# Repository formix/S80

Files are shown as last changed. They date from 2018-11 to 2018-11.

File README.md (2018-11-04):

# S80
## S80 - Stackable retro Z80 computer
Welcome to the primary source of information regarding the S80.

For in depth information on the S80 hardware, please visit: [S80 website](http://users.telenet.be/pynckels/s80_retro.html)

The S80 facebook page can be found at: [S80 on Facebook](https://www.facebook.com/S80computer)

The issues section of this repository will serve as discussion forum on everything around the S80 (actual and future hardware, actual and future software, inspirational ideas, questions, ...): [S80 community and forum](https://github.com/PaintedBlck/S80/issues)

We hope this is the beginning of a growing community of people around the S80 who want to inspire others, learn, help, discuss, ... See also the Code of Conduct, since this document describes how we see collaboration and having fun.

## S80C - Small Z80 Cp/m computer

This is a project in the making. The first discussions on the functionality have begun on the [S80 community and forum in Issue 12](https://github.com/PaintedBlck/S80/issues/12).

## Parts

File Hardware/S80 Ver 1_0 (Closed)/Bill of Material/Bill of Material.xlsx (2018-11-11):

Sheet: Bill of Material (Data)
PCB | Item | Item_value | Item_footprint | Item_name
/Breakout 2in/ | J801 | Header Female 02x20 Pins 11mm | Pynckels:PinSocket_2x20_P2.54mm_Vertical | Conn_02x20
/Breakout 2in/ | J802 | Header Female 01x08 Pins 11mm | Connector_PinSocket_2.54mm:PinSocket_1x08_P2.54mm_Vertical | Conn_01x08
/Breakout 2in/ | J803 | Header Female 01x08 Pins 11mm | Connector_PinSocket_2.54mm:PinSocket_1x08_P2.54mm_Vertical | Conn_01x08
/Breakout 2in/ | PCB | PCB | PCB 8 | PCB
/Breakout 2in/ | Screw | Screw M3 | PCB 8 | Screw
/Breakout 2in/ | Screw | Screw M3 | PCB 8 | Screw
/Breakout 2in/ | Screw | Screw M3 | PCB 8 | Screw
/Breakout 2in/ | Screw | Screw M3 | PCB 8 | Screw
/Breakout 2in/ | Screw | Screw M3 | PCB 8 | Screw
/Breakout 2in/ | Screw | Screw M3 | PCB 8 | Screw
/Breakout 2in/ | Screw | Screw M3 | PCB 8 | Screw
/Breakout 2in/ | Screw | Screw M3 | PCB 8 | Screw
/Breakout 2in/ | Spacer | Spacer 10mm 2xM3 inner | PCB 8 | Spacer
/Breakout 2in/ | Spacer | Spacer 10mm 2xM3 inner | PCB 8 | Spacer
/Breakout 2in/ | Spacer | Spacer 10mm 2xM3 inner | PCB 8 | Spacer
/Breakout 2in/ | Spacer | Spacer 10mm 2xM3 inner | PCB 8 | Spacer
/Breakout 7in/ | J901 | Header Female 02x20 Pins 11mm | Pynckels:PinSocket_2x20_P2.54mm_Vertical | Conn_02x20
/Breakout 7in/ | J902 | Header Female 01x08 Pins 11mm | Connector_PinSocket_2.54mm:PinSocket_1x08_P2.54mm_Vertical | Conn_01x08
/Breakout 7in/ | J903 | Header Female 01x08 Pins 11mm | Connector_PinSocket_2.54mm:PinSocket_1x08_P2.54mm_Vertical | Conn_01x08
/Breakout 7in/ | PCB | PCB | PCB 9 | PCB
/Breakout 7in/ | Screw | Screw M3 | PCB 9 | Screw
/Breakout 7in/ | Screw | Screw M3 | PCB 9 | Screw
/Breakout 7in/ | Screw | Screw M3 | PCB 9 | Screw
/Breakout 7in/ | Screw | Screw M3 | PCB 9 | Screw
/Breakout 7in/ | Screw | Screw M3 | PCB 9 | Screw
/Breakout 7in/ | Screw | Screw M3 | PCB 9 | Screw
/Breakout 7in/ | Screw | Screw M3 | PCB 9 | Screw
/Breakout 7in/ | Screw | Screw M3 | PCB 9 | Screw
/Breakout 7in/ | Spacer | Spacer 10mm 2xM3 inner | PCB 9 | Spacer
/Breakout 7in/ | Spacer | Spacer 10mm 2xM3 inner | PCB 9 | Spacer
/Breakout 7in/ | Spacer | Spacer 10mm 2xM3 inner | PCB 9 | Spacer
/Breakout 7in/ | Spacer | Spacer 10mm 2xM3 inner | PCB 9 | Spacer
/Clock Power Reset/ | C201 | 100pf min 10V | Capacitor_THT:C_Disc_D5.0mm_W2.5mm_P5.00mm | C
/Clock Power Reset/ | C202 | 100pf min 10V | Capacitor_THT:C_Disc_D5.0mm_W2.5mm_P5.00mm | C
/Clock Power Reset/ | C203 | 100pf min 10V | Capacitor_THT:C_Disc_D5.0mm_W2.5mm_P5.00mm | C
/Clock Power Reset/ | C204 | 100pf min 10V | Capacitor_THT:C_Disc_D5.0mm_W2.5mm_P5.00mm | C
/Clock Power Reset/ | C205 | 100pf min 10V | Capacitor_THT:C_Disc_D5.0mm_W2.5mm_P5.00mm | C
/Clock Power Reset/ | C206 | 100pf min 10V | Capacitor_THT:C_Disc_D5.0mm_W2.5mm_P5.00mm | C
/Clock Power Reset/ | C207 | 100pf min 10V | Capacitor_THT:C_Disc_D5.0mm_W2.5mm_P5.00mm | C
/Clock Power Reset/ | C208 | 100pf min 10V | Capacitor_THT:C_Disc_D5.0mm_W2.5mm_P5.00mm | C
/Clock Power Reset/ | C401 | 100pf min 10V | Capacitor_THT:C_Disc_D5.0mm_W2.5mm_P5.00mm | C
/Clock Power Reset/ | C601 | 22μF min 10V | Capacitor_THT:CP_Radial_D6.3mm_P2.50mm | C
/Clock Power Reset/ | C602 | 100pf min 10V | Capacitor_THT:C_Disc_D5.0mm_W2.5mm_P5.00mm | C
/Clock Power Reset/ | D201 | 5V1 | Pynckels:D_Zener_Reverse_Biased | D_Zener
/Clock Power Reset/ | D401 | 5V1 | Pynckels:D_Zener_Reverse_Biased | D_Zener
/Clock Power Reset/ | J201 | Header Female 02x20 Pins 11mm | Pynckels:PinSocket_2x20_P2.54mm_Vertical | Conn_02x20
/Clock Power Reset/ | J202 | Header Female 01x08 Pins 11mm | Connector_PinSocket_2.54mm:PinSocket_1x08_P2.54mm_Vertical | Conn_01x08
/Clock Power Reset/ | J203 | Header Female 01x08 Pins 11mm | Connector_PinSocket_2.54mm:PinSocket_1x08_P2.54mm_Vertical | Conn_01x08
/Clock Power Reset/ | J404 | Header Male 01x04 Pins 7mm | Connector_PinHeader_2.54mm:PinHeader_1x04_P2.54mm_Vertical | Jumper
/Clock Power Reset/ | JP201 | Header Male 02x01 Pins 7mm | Connector_PinHeader_2.54mm:PinHeader_1x02_P2.54mm_Vertical | Jumper
/Clock Power Reset/ | JP202 | Header Male 02x01 Pins 7mm | Connector_PinHeader_2.54mm:PinHeader_1x02_P2.54mm_Vertical | Jumper
/Clock Power Reset/ | JP203 | Header Male 02x01 Pins 7mm | Connector_PinHeader_2.54mm:PinHeader_1x02_P2.54mm_Vertical | Jumper
/Clock Power Reset/ | JP204 | Header Male 02x01 Pins 7mm | Connector_PinHeader_2.54mm:PinHeader_1x02_P2.54mm_Vertical | Jumper
/Clock Power Reset/ | JP205 | Header Male 02x01 Pins 7mm | Connector_PinHeader_2.54mm:PinHeader_1x02_P2.54mm_Vertical | Jumper
/Clock Power Reset/ | JP206 | Header Male 02x01 Pins 7mm | Connector_PinHeader_2.54mm:PinHeader_1x02_P2.54mm_Vertical | Jumper
/Clock Power Reset/ | JP207 | Header Male 02x01 Pins 7mm | Connector_PinHeader_2.54mm:PinHeader_1x02_P2.54mm_Vertical | Jumper
/Clock Power Reset/ | JP208 | Header Male 02x01 Pins 7mm | Connector_PinHeader_2.54mm:PinHeader_1x02_P2.54mm_Vertical | Jumper
/Clock Power Reset/ | Jumper | Jumper | Jumper | Jumper
/Clock Power Reset/ | PCB | PCB | PCB 2 4 6 | PCB
/Clock Power Reset/ | R601 | 1K 5% | Resistor_THT:R_Axial_DIN0207_L6.3mm_D2.5mm_P7.62mm_Horizontal | R
/Clock Power Reset/ | R602 | 1K 5% | Resistor_THT:R_Axial_DIN0207_L6.3mm_D2.5mm_P7.62mm_Horizontal | R
/Clock Power Reset/ | Screw | Screw M3 | PCB 2 4 6 | Screw
/Clock Power Reset/ | Screw | Screw M3 | PCB 2 4 6 | Screw
/Clock Power Reset/ | Screw | Screw M3 | PCB 2 4 6 | Screw
/Clock Power Reset/ | Screw | Screw M3 | PCB 2 4 6 | Screw
/Clock Power Reset/ | Screw | Screw M3 | PCB 2 4 6 | Screw
/Clock Power Reset/ | Screw | Screw M3 | PCB 2 4 6 | Screw
/Clock Power Reset/ | Screw | Screw M3 | PCB 2 4 6 | Screw
/Clock Power Reset/ | Screw | Screw M3 | PCB 2 4 6 | Screw
/Clock Power Reset/ | Spacer | Spacer 10mm 2xM3 inner | PCB 2 4 6 | Spacer
/Clock Power Reset/ | Spacer | Spacer 10mm 2xM3 inner | PCB 2 4 6 | Spacer
/Clock Power Reset/ | Spacer | Spacer 10mm 2xM3 inner | PCB 2 4 6 | Spacer
/Clock Power Reset/ | Spacer | Spacer 10mm 2xM3 inner | PCB 2 4 6 | Spacer
/Clock Power Reset/ | SW601 | Switch Push | Button_Switch_THT:SW_PUSH_6mm | Button
/Clock Power Reset/ | U601 | 74LS14 | Package_DIP:DIP-14_W7.62mm | Hex Inverter Schmitt Trigger74LS14
/Clock Power Reset/ | US601 | Socket 14-pin tulp | Package_DIP:DIP-14_W7.62mm | Socket 14-pin tulp
/Clock Power Reset/ | X207 | Oscillator 8Mhz | Oscillator:Oscillator_DIP-14 | XO32
/Memory/ | C301 | 100pf min 10V | Capacitor_THT:C_Disc_D5.0mm_W2.5mm_P5.00mm | C
/Memory/ | C302 | 100pf min 10V | Capacitor_THT:C_Disc_D5.0mm_W2.5mm_P5.00mm | C
/Memory/ | C303 | 100pf min 10V | Capacitor_THT:C_Disc_D5.0mm_W2.5mm_P5.00mm | C
/Memory/ | C304 | 100pf min 10V | Capacitor_THT:C_Disc_D5.0mm_W2.5mm_P5.00mm | C
/Memory/ | C305 | 100pf min 10V | Capacitor_THT:C_Disc_D5.0mm_W2.5mm_P5.00mm | C
/Memory/ | C306 | 100pf min 10V | Capacitor_THT:C_Disc_D5.0mm_W2.5mm_P5.00mm | C
/Memory/ | C307 | 100pf min 10V | Capacitor_THT:C_Disc_D5.0mm_W2.5mm_P5.00mm | C
/Memory/ | C308 | 100pf min 10V | Capacitor_THT:C_Disc_D5.0mm_W2.5mm_P5.00mm | C
/Memory/ | J301 | Header Female 02x20 Pins 11mm | Pynckels:PinSocket_2x20_P2.54mm_Vertical | Conn_02x20
/Memory/ | J302 | Header Female 01x08 Pins 11mm | Connector_PinSocket_2.54mm:PinSocket_1x08_P2.54mm_Vertical | Conn_01x08
/Memory/ | J303 | Header Female 01x08 Pins 11mm | Connector_PinSocket_2.54mm:PinSocket_1x08_P2.54mm_Vertical | Conn_01x08
/Memory/ | J304 | Header Male 02x08 Pins 7mm | Connector_PinHeader_2.54mm:PinHeader_2x08_P2.54mm_Vertical | Jumper
/Memory/ | J305 | Header Male 02x03 Pins 7mm | Connector_PinHeader_2.54mm:PinHeader_2x03_P2.54mm_Vertical | Jumper
/Memory/ | Jumper | Jumper | Jumper | Jumper
/Memory/ | Jumper | Jumper | Jumper | Jumper
/Memory/ | Jumper | Jumper | Jumper | Jumper
/Memory/ | Jumper | Jumper | Jumper | Jumper
/Memory/ | Jumper | Jumper | Jumper | Jumper
/Memory/ | Jumper | Jumper | Jumper | Jumper
/Memory/ | Jumper | Jumper | Jumper | Jumper
/Memory/ | Jumper | Jumper | Jumper | Jumper
/Memory/ | Jumper | Jumper | Jumper | Jumper
/Memory/ | PCB | PCB | PCB 3 | PCB
/Memory/ | R301 | 220 5% | Resistor_THT:R_Axial_DIN0207_L6.3mm_D2.5mm_P7.62mm_Horizontal | R
/Memory/ | R302 | 220 5% | Resistor_THT:R_Axial_DIN0207_L6.3mm_D2.5mm_P7.62mm_Horizontal | R
/Memory/ | R303 | 220 5% | Resistor_THT:R_Axial_DIN0207_L6.3mm_D2.5mm_P7.62mm_Horizontal | R
/Memory/ | R304 | 220 5% | Resistor_THT:R_Axial_DIN0207_L6.3mm_D2.5mm_P7.62mm_Horizontal | R
/Memory/ | R305 | 220 5% | Resistor_THT:R_Axial_DIN0207_L6.3mm_D2.5mm_P7.62mm_Horizontal | R
/Memory/ | R306 | 220 5% | Resistor_THT:R_Axial_DIN0207_L6.3mm_D2.5mm_P7.62mm_Horizontal | R
/Memory/ | R307 | 220 5% | Resistor_THT:R_Axial_DIN0207_L6.3mm_D2.5mm_P7.62mm_Horizontal | R
/Memory/ | R308 | 220 5% | Resistor_THT:R_Axial_DIN0207_L6.3mm_D2.5mm_P7.62mm_Horizontal | R
/Memory/ | R309 | 5K 5% | Resistor_THT:R_Axial_DIN0207_L6.3mm_D2.5mm_P7.62mm_Horizontal | R
/Memory/ | R310 | 5K 5% | Resistor_THT:R_Axial_DIN0207_L6.3mm_D2.5mm_P7.62mm_Horizontal | R
/Memory/ | R311 | 5K 5% | Resistor_THT:R_Axial_DIN0207_L6.3mm_D2.5mm_P7.62mm_Horizontal | R
/Memory/ | Screw | Screw M3 | PCB 3 | Screw
/Memory/ | Screw | Screw M3 | PCB 3 | Screw
/Memory/ | Screw | Screw M3 | PCB 3 | Screw
/Memory/ | Screw | Screw M3 | PCB 3 | Screw
/Memory/ | Screw | Screw M3 | PCB 3 | Screw
/Memory/ | Screw | Screw M3 | PCB 3 | Screw
/Memory/ | Screw | Screw M3 | PCB 3 | Screw
/Memory/ | Screw | Screw M3 | PCB 3 | Screw
/Memory/ | Spacer | Spacer 10mm 2xM3 inner | PCB 3 | Spacer
/Memory/ | Spacer | Spacer 10mm 2xM3 inner | PCB 3 | Spacer
/Memory/ | Spacer | Spacer 10mm 2xM3 inner | PCB 3 | Spacer
/Memory/ | Spacer | Spacer 10mm 2xM3 inner | PCB 3 | Spacer
/Memory/ | U301 | 74LS32 | Package_DIP:DIP-14_W7.62mm | Quad 2 Input OR Gate 74LS32
/Memory/ | U302 | AT28C256 | Package_DIP:DIP-28_W15.24mm | AT28C256-15PC
/Memory/ | U303 | 74LS04 | Package_DIP:DIP-14_W7.62mm | Hex Inverter 74LS04
/Memory/ | U304 | AT28C256 | Package_DIP:DIP-28_W15.24mm | AT28C256-15PC
/Memory/ | U305 | AT28C256 | Package_DIP:DIP-28_W15.24mm | AT28C256-15PC
/Memory/ | U306 | HM62256 | Package_DIP:DIP-28_W15.24mm | HM62256
/Memory/ | U307 | HM62256 | Package_DIP:DIP-28_W15.24mm | HM62256
/Memory/ | U308 | 74LS682 | Package_DIP:DIP-20_W7.62mm | 8-bit Magnitude Comparator 74LS682
/Memory/ | US301 | Socket 14-pin tulp | Package_DIP:DIP-14_W7.62mm | Socket 14-pin tulp
/Memory/ | US302 | Socket 28-pin tulp | Package_DIP:DIP-28_W15.24mm | Socket 28-pin tulp
/Memory/ | US303 | Socket 14-pin tulp | Package_DIP:DIP-14_W7.62mm | Socket 14-pin tulp
/Memory/ | US304 | Socket 28-pin tulp | Package_DIP:DIP-28_W15.24mm | Socket 28-pin tulp
/Memory/ | US305 | Socket 28-pin tulp | Package_DIP:DIP-28_W15.24mm | Socket 28-pin tulp
/Memory/ | US306 | Socket 28-pin tulp | Package_DIP:DIP-28_W15.24mm | Socket 28-pin tulp
/Memory/ | US306 | Socket 28-pin tulp | Package_DIP:DIP-28_W15.24mm | Socket 28-pin tulp
/Memory/ | US308 | Socket 20-pin tulp | Package_DIP:DIP-20_W7.62mm | Socket 20-pin tulp
/Processor/ | C501 | 100pf min 10V | Capacitor_THT:C_Disc_D5.0mm_W2.5mm_P5.00mm | C
/Processor/ | C502 | 100pf min 10V | Capacitor_THT:C_Disc_D5.0mm_W2.5mm_P5.00mm | C
/Processor/ | C503 | 100pf min 10V | Capacitor_THT:C_Disc_D5.0mm_W2.5mm_P5.00mm | C
/Processor/ | C504 | 100pf min 10V | Capacitor_THT:C_Disc_D5.0mm_W2.5mm_P5.00mm | C
/Processor/ | C505 | 100pf min 10V | Capacitor_THT:C_Disc_D5.0mm_W2.5mm_P5.00mm | C
/Processor/ | C506 | 100pf min 10V | Capacitor_THT:C_Disc_D5.0mm_W2.5mm_P5.00mm | C
/Processor/ | D501 | D | Pynckels:D_1N4148_Reverse_Biased | D
/Processor/ | D502 | D | Pynckels:D_1N4148_Reverse_Biased | D
/Processor/ | D503 | D | Pynckels:D_1N4148_Reverse_Biased | D
/Processor/ | D504 | D | Pynckels:D_1N4148_Reverse_Biased | D
/Processor/ | D505 | D | Pynckels:D_1N4148_Reverse_Biased | D
/Processor/ | D506 | D | Pynckels:D_1N4148_Reverse_Biased | D
/Processor/ | D507 | D | Pynckels:D_1N4148_Reverse_Biased | D
/Processor/ | D508 | D | Pynckels:D_1N4148_Reverse_Biased | D
/Processor/ | D509 | D | Pynckels:D_1N4148_Reverse_Biased | D
/Processor/ | D510 | D | Pynckels:D_1N4148_Reverse_Biased | D
/Processor/ | D511 | D | Pynckels:D_1N4148_Reverse_Biased | D
/Processor/ | D512 | D | Pynckels:D_1N4148_Reverse_Biased | D
/Processor/ | J501 | Header Female 02x20 Pins 11mm | Pynckels:PinSocket_2x20_P2.54mm_Vertical | Conn_02x20
/Processor/ | J502 | Header Female 01x08 Pins 11mm | Connector_PinSocket_2.54mm:PinSocket_1x08_P2.54mm_Vertical | Conn_01x08
/Processor/ | J503 | Header Female 01x08 Pins 11mm | Connector_PinSocket_2.54mm:PinSocket_1x08_P2.54mm_Vertical | Conn_01x08
/Processor/ | PCB | PCB | PCB 5 | PCB
/Processor/ | R501 | 5K 5% | Resistor_THT:R_Axial_DIN0207_L6.3mm_D2.5mm_P7.62mm_Horizontal | R
/Processor/ | R502 | 5K 5% | Resistor_THT:R_Axial_DIN0207_L6.3mm_D2.5mm_P7.62mm_Horizontal | R
/Processor/ | R503 | 5K 5% | Resistor_THT:R_Axial_DIN0207_L6.3mm_D2.5mm_P7.62mm_Horizontal | R
/Processor/ | R504 | 5K 5% | Resistor_THT:R_Axial_DIN0207_L6.3mm_D2.5mm_P7.62mm_Horizontal | R
/Processor/ | R505 | 5K 5% | Resistor_THT:R_Axial_DIN0207_L6.3mm_D2.5mm_P7.62mm_Horizontal | R
/Processor/ | R506 | 5K 5% | Resistor_THT:R_Axial_DIN0207_L6.3mm_D2.5mm_P7.62mm_Horizontal | R
/Processor/ | R507 | 220 5% | Resistor_THT:R_Axial_DIN0207_L6.3mm_D2.5mm_P7.62mm_Horizontal | R
/Processor/ | R508 | 220 5% | Resistor_THT:R_Axial_DIN0207_L6.3mm_D2.5mm_P7.62mm_Horizontal | R
/Processor/ | R509 | 220 5% | Resistor_THT:R_Axial_DIN0207_L6.3mm_D2.5mm_P7.62mm_Horizontal | R
/Processor/ | R510 | 220 5% | Resistor_THT:R_Axial_DIN0207_L6.3mm_D2.5mm_P7.62mm_Horizontal | R
/Processor/ | R511 | 220 5% | Resistor_THT:R_Axial_DIN0207_L6.3mm_D2.5mm_P7.62mm_Horizontal | R
/Processor/ | R512 | 220 5% | Resistor_THT:R_Axial_DIN0207_L6.3mm_D2.5mm_P7.62mm_Horizontal | R
/Processor/ | Screw | Screw M3 | PCB 5 | Screw
/Processor/ | Screw | Screw M3 | PCB 5 | Screw
/Processor/ | Screw | Screw M3 | PCB 5 | Screw
/Processor/ | Screw | Screw M3 | PCB 5 | Screw
/Processor/ | Screw | Screw M3 | PCB 5 | Screw
/Processor/ | Screw | Screw M3 | PCB 5 | Screw
/Processor/ | Screw | Screw M3 | PCB 5 | Screw
/Processor/ | Screw | Screw M3 | PCB 5 | Screw
/Processor/ | Spacer | Spacer 10mm 2xM3 inner | PCB 5 | Spacer
/Processor/ | Spacer | Spacer 10mm 2xM3 inner | PCB 5 | Spacer
/Processor/ | Spacer | Spacer 10mm 2xM3 inner | PCB 5 | Spacer
/Processor/ | Spacer | Spacer 10mm 2xM3 inner | PCB 5 | Spacer
/Processor/ | U501 | Z80CPU | Package_DIP:DIP-40_W15.24mm | Z80CPU
/Processor/ | U502 | 74LS04 | Package_DIP:DIP-14_W7.62mm | Hex Inverter 74LS04
/Processor/ | U503 | 74LS244 | Package_DIP:DIP-20_W7.62mm | Octal Buffer 74LS244
/Processor/ | U504 | 74LS244 | Package_DIP:DIP-20_W7.62mm | Octal Buffer 74LS244
/Processor/ | U505 | 74LS245 | Package_DIP:DIP-20_W7.62mm | Octal Bus Tranceiver 74LS245
/Processor/ | U506 | 74LS244 | Package_DIP:DIP-20_W7.62mm | Octal Buffer 74LS244
/Processor/ | US501 | Socket 40-pin tulp | Package_DIP:DIP-40_W15.24mm | Socket 40-pin tulp
/Processor/ | US502 | Socket 14-pin tulp | Package_DIP:DIP-14_W7.62mm | Socket 14-pin tulp
/Processor/ | US503 | Socket 20-pin tulp | Package_DIP:DIP-20_W7.62mm | Socket 20-pin tulp
/Processor/ | US504 | Socket 20-pin tulp | Package_DIP:DIP-20_W7.62mm | Socket 20-pin tulp
/Processor/ | US505 | Socket 20-pin tulp | Package_DIP:DIP-20_W7.62mm | Socket 20-pin tulp
/Processor/ | US506 | Socket 20-pin tulp | Package_DIP:DIP-20_W7.62mm | Socket 20-pin tulp
/Serial/ | C701 | 100pf min 10V | Capacitor_THT:C_Disc_D5.0mm_W2.5mm_P5.00mm | C
/Serial/ | C702 | 100pf min 10V | Capacitor_THT:C_Disc_D5.0mm_W2.5mm_P5.00mm | C
/Serial/ | C703 | 100pf min 10V | Capacitor_THT:C_Disc_D5.0mm_W2.5mm_P5.00mm | C
/Serial/ | C704 | 100pf min 10V | Capacitor_THT:C_Disc_D5.0mm_W2.5mm_P5.00mm | C
/Serial/ | J701 | Header Female 02x20 Pins 11mm | Pynckels:PinSocket_2x20_P2.54mm_Vertical | Conn_02x20
/Serial/ | J702 | Header Female 01x08 Pins 11mm | Connector_PinSocket_2.54mm:PinSocket_1x08_P2.54mm_Vertical | Conn_01x08
/Serial/ | J703 | Header Female 01x08 Pins 11mm | Connector_PinSocket_2.54mm:PinSocket_1x08_P2.54mm_Vertical | Conn_01x08
/Serial/ | J704 | Header Male 02x05 Pins 7mm | Connector_PinHeader_2.54mm:PinHeader_2x05_P2.54mm_Vertical | Jumper
/Serial/ | Jumper | Jumper | Jumper | Jumper
/Serial/ | Jumper | Jumper | Jumper | Jumper
/Serial/ | Jumper | Jumper | Jumper | Jumper
/Serial/ | Jumper | Jumper | Jumper | Jumper
/Serial/ | Jumper | Jumper | Jumper | Jumper
/Serial/ | PCB | PCB | PCB 7 | PCB
/Serial/ | R701 | 5K 5% | Resistor_THT:R_Axial_DIN0207_L6.3mm_D2.5mm_P7.62mm_Horizontal | R
/Serial/ | R702 | 5K 5% | Resistor_THT:R_Axial_DIN0207_L6.3mm_D2.5mm_P7.62mm_Horizontal | R
/Serial/ | R703 | 5K 5% | Resistor_THT:R_Axial_DIN0207_L6.3mm_D2.5mm_P7.62mm_Horizontal | R
/Serial/ | R704 | 5K 5% | Resistor_THT:R_Axial_DIN0207_L6.3mm_D2.5mm_P7.62mm_Horizontal | R
/Serial/ | R705 | 5K 5% | Resistor_THT:R_Axial_DIN0207_L6.3mm_D2.5mm_P7.62mm_Horizontal | R
/Serial/ | Screw | Screw M3 | PCB 7 | Screw
/Serial/ | Screw | Screw M3 | PCB 7 | Screw
/Serial/ | Screw | Screw M3 | PCB 7 | Screw
/Serial/ | Screw | Screw M3 | PCB 7 | Screw
/Serial/ | Screw | Screw M3 | PCB 7 | Screw
/Serial/ | Screw | Screw M3 | PCB 7 | Screw
/Serial/ | Screw | Screw M3 | PCB 7 | Screw
/Serial/ | Screw | Screw M3 | PCB 7 | Screw
/Serial/ | Spacer | Spacer 10mm 2xM3 inner | PCB 7 | Spacer
/Serial/ | Spacer | Spacer 10mm 2xM3 inner | PCB 7 | Spacer
/Serial/ | Spacer | Spacer 10mm 2xM3 inner | PCB 7 | Spacer
/Serial/ | Spacer | Spacer 10mm 2xM3 inner | PCB 7 | Spacer
/Serial/ | U701 | 16C550 | Package_DIP:DIP-40_W15.24mm | USART 16C550
/Serial/ | U702 | 74LS04 | Package_DIP:DIP-14_W7.62mm | Hex Inverter 74LS04
/Serial/ | U703 | 74LS682 | Package_DIP:DIP-20_W7.62mm | 8-bit Magnitude Comparator 74LS682
/Serial/ | US701 | Socket 40-pin tulp | Package_DIP:DIP-40_W15.24mm | Socket 40-pin tulp
/Serial/ | US702 | Socket 14-pin tulp | Package_DIP:DIP-14_W7.62mm | Socket 14-pin tulp
/Serial/ | US703 | Socket 20-pin tulp | Package_DIP:DIP-20_W7.62mm | Socket 20-pin tulp
/Serial/ | X701 | Oscillator 1.8432Mhz | Oscillator:Oscillator_DIP-14 | XO32
Test Point Breakout 2in (option) | Brk801 | Test Point | Pynckels:pad_0_8mm_1_5mm | Vero Loop Terminal 01x01 1.02mm
Test Point Breakout 2in (option) | Brk802 | Test Point | Pynckels:pad_0_8mm_1_5mm | Vero Loop Terminal 01x01 1.02mm
Test Point Breakout 2in (option) | Brk803 | Test Point | Pynckels:pad_0_8mm_1_5mm | Vero Loop Terminal 01x01 1.02mm
Test Point Breakout 2in (option) | Brk804 | Test Point | Pynckels:pad_0_8mm_1_5mm | Vero Loop Terminal 01x01 1.02mm
Test Point Breakout 2in (option) | Brk805 | Test Point | Pynckels:pad_0_8mm_1_5mm | Vero Loop Terminal 01x01 1.02mm
Test Point Breakout 2in (option) | Brk806 | Test Point | Pynckels:pad_0_8mm_1_5mm | Vero Loop Terminal 01x01 1.02mm
Test Point Breakout 2in (option) | Brk807 | Test Point | Pynckels:pad_0_8mm_1_5mm | Vero Loop Terminal 01x01 1.02mm
Test Point Breakout 2in (option) | Brk808 | Test Point | Pynckels:pad_0_8mm_1_5mm | Vero Loop Terminal 01x01 1.02mm
Test Point Breakout 2in (option) | Brk809 | Test Point | Pynckels:pad_0_8mm_1_5mm | Vero Loop Terminal 01x01 1.02mm
Test Point Breakout 2in (option) | Brk810 | Test Point | Pynckels:pad_0_8mm_1_5mm | Vero Loop Terminal 01x01 1.02mm
Test Point Breakout 2in (option) | Brk811 | Test Point | Pynckels:pad_0_8mm_1_5mm | Vero Loop Terminal 01x01 1.02mm
Test Point Breakout 2in (option) | Brk812 | Test Point | Pynckels:pad_0_8mm_1_5mm | Vero Loop Terminal 01x01 1.02mm
Test Point Breakout 2in (option) | Brk813 | Test Point | Pynckels:pad_0_8mm_1_5mm | Vero Loop Terminal 01x01 1.02mm
Test Point Breakout 2in (option) | Brk814 | Test Point | Pynckels:pad_0_8mm_1_5mm | Vero Loop Terminal 01x01 1.02mm
Test Point Breakout 2in (option) | Brk815 | Test Point | Pynckels:pad_0_8mm_1_5mm | Vero Loop Terminal 01x01 1.02mm
Test Point Breakout 2in (option) | Brk816 | Test Point | Pynckels:pad_0_8mm_1_5mm | Vero Loop Terminal 01x01 1.02mm
Test Point Breakout 2in (option) | Brk817 | Test Point | Pynckels:pad_0_8mm_1_5mm | Vero Loop Terminal 01x01 1.02mm
Test Point Breakout 2in (option) | Brk818 | Test Point | Pynckels:pad_0_8mm_1_5mm | Vero Loop Terminal 01x01 1.02mm
Test Point Breakout 2in (option) | Brk819 | Test Point | Pynckels:pad_0_8mm_1_5mm | Vero Loop Terminal 01x01 1.02mm
Test Point Breakout 2in (option) | Brk820 | Test Point | Pynckels:pad_0_8mm_1_5mm | Vero Loop Terminal 01x01 1.02mm
Test Point Breakout 2in (option) | Brk821 | Test Point | Pynckels:pad_0_8mm_1_5mm | Vero Loop Terminal 01x01 1.02mm
Test Point Breakout 2in (option) | Brk822 | Test Point | Pynckels:pad_0_8mm_1_5mm | Vero Loop Terminal 01x01 1.02mm
Test Point Breakout 2in (option) | Brk823 | Test Point | Pynckels:pad_0_8mm_1_5mm | Vero Loop Terminal 01x01 1.02mm
Test Point Breakout 2in (option) | Brk824 | Test Point | Pynckels:pad_0_8mm_1_5mm | Vero Loop Terminal 01x01 1.02mm
Test Point Breakout 2in (option) | Brk825 | Test Point | Pynckels:pad_0_8mm_1_5mm | Vero Loop Terminal 01x01 1.02mm
Test Point Breakout 2in (option) | Brk826 | Test Point | Pynckels:pad_0_8mm_1_5mm | Vero Loop Terminal 01x01 1.02mm
Test Point Breakout 2in (option) | Brk827 | Test Point | Pynckels:pad_0_8mm_1_5mm | Vero Loop Terminal 01x01 1.02mm
Test Point Breakout 2in (option) | Brk828 | Test Point | Pynckels:pad_0_8mm_1_5mm | Vero Loop Terminal 01x01 1.02mm
Test Point Breakout 2in (option) | Brk829 | Test Point | Pynckels:pad_0_8mm_1_5mm | Vero Loop Terminal 01x01 1.02mm
Test Point Breakout 2in (option) | Brk830 | Test Point | Pynckels:pad_0_8mm_1_5mm | Vero Loop Terminal 01x01 1.02mm
Test Point Breakout 2in (option) | Brk831 | Test Point | Pynckels:pad_0_8mm_1_5mm | Vero Loop Terminal 01x01 1.02mm
Test Point Breakout 2in (option) | Brk832 | Test Point | Pynckels:pad_0_8mm_1_5mm | Vero Loop Terminal 01x01 1.02mm
Test Point Breakout 2in (option) | Brk833 | Test Point | Pynckels:pad_0_8mm_1_5mm | Vero Loop Terminal 01x01 1.02mm
Test Point Breakout 2in (option) | Brk834 | Test Point | Pynckels:pad_0_8mm_1_5mm | Vero Loop Terminal 01x01 1.02mm
Test Point Breakout 2in (option) | Brk835 | Test Point | Pynckels:pad_0_8mm_1_5mm | Vero Loop Terminal 01x01 1.02mm
Test Point Breakout 2in (option) | Brk836 | Test Point | Pynckels:pad_0_8mm_1_5mm | Vero Loop Terminal 01x01 1.02mm
Test Point Breakout 2in (option) | Brk837 | Test Point | Pynckels:pad_0_8mm_1_5mm | Vero Loop Terminal 01x01 1.02mm
Test Point Breakout 2in (option) | Brk838 | Test Point | Pynckels:pad_0_8mm_1_5mm | Vero Loop Terminal 01x01 1.02mm
Test Point Breakout 2in (option) | Brk839 | Test Point | Pynckels:pad_0_8mm_1_5mm | Vero Loop Terminal 01x01 1.02mm
Test Point Breakout 2in (option) | Brk840 | Test Point | Pynckels:pad_0_8mm_1_5mm | Vero Loop Terminal 01x01 1.02mm
Test Point Breakout 2in (option) | Brk841 | Test Point | Pynckels:pad_0_8mm_1_5mm | Vero Loop Terminal 01x01 1.02mm
Test Point Breakout 2in (option) | Brk842 | Test Point | Pynckels:pad_0_8mm_1_5mm | Vero Loop Terminal 01x01 1.02mm
Test Point Breakout 2in (option) | Brk843 | Test Point | Pynckels:pad_0_8mm_1_5mm | Vero Loop Terminal 01x01 1.02mm
Test Point Breakout 2in (option) | Brk844 | Test Point | Pynckels:pad_0_8mm_1_5mm | Vero Loop Terminal 01x01 1.02mm
Test Point Breakout 2in (option) | Brk845 | Test Point | Pynckels:pad_0_8mm_1_5mm | Vero Loop Terminal 01x01 1.02mm
Test Point Breakout 2in (option) | Brk846 | Test Point | Pynckels:pad_0_8mm_1_5mm | Vero Loop Terminal 01x01 1.02mm
Test Point Breakout 2in (option) | Brk847 | Test Point | Pynckels:pad_0_8mm_1_5mm | Vero Loop Terminal 01x01 1.02mm
Test Point Breakout 2in (option) | Brk848 | Test Point | Pynckels:pad_0_8mm_1_5mm | Vero Loop Terminal 01x01 1.02mm
Test Point Breakout 2in (option) | Brk849 | Test Point | Pynckels:pad_0_8mm_1_5mm | Vero Loop Terminal 01x01 1.02mm
Test Point Breakout 2in (option) | Brk850 | Test Point | Pynckels:pad_0_8mm_1_5mm | Vero Loop Terminal 01x01 1.02mm
Test Point Breakout 2in (option) | Brk851 | Test Point | Pynckels:pad_0_8mm_1_5mm | Vero Loop Terminal 01x01 1.02mm
Test Point Breakout 2in (option) | Brk852 | Test Point | Pynckels:pad_0_8mm_1_5mm | Vero Loop Terminal 01x01 1.02mm
Test Point Breakout 2in (option) | Brk853 | Test Point | Pynckels:pad_0_8mm_1_5mm | Vero Loop Terminal 01x01 1.02mm
Test Point Breakout 2in (option) | Brk854 | Test Point | Pynckels:pad_0_8mm_1_5mm | Vero Loop Terminal 01x01 1.02mm
Test Point Breakout 2in (option) | Brk855 | Test Point | Pynckels:pad_0_8mm_1_5mm | Vero Loop Terminal 01x01 1.02mm
Test Point Breakout 2in (option) | Brk856 | Test Point | Pynckels:pad_0_8mm_1_5mm | Vero Loop Terminal 01x01 1.02mm
Test Point Breakout 7in (option) | Brk901 | Test Point | Pynckels:pad_0_8mm_1_5mm | Vero Loop Terminal 01x01 1.02mm
Test Point Breakout 7in (option) | Brk902 | Test Point | Pynckels:pad_0_8mm_1_5mm | Vero Loop Terminal 01x01 1.02mm
Test Point Breakout 7in (option) | Brk903 | Test Point | Pynckels:pad_0_8mm_1_5mm | Vero Loop Terminal 01x01 1.02mm
Test Point Breakout 7in (option) | Brk904 | Test Point | Pynckels:pad_0_8mm_1_5mm | Vero Loop Terminal 01x01 1.02mm
Test Point Breakout 7in (option) | Brk905 | Test Point | Pynckels:pad_0_8mm_1_5mm | Vero Loop Terminal 01x01 1.02mm
Test Point Breakout 7in (option) | Brk906 | Test Point | Pynckels:pad_0_8mm_1_5mm | Vero Loop Terminal 01x01 1.02mm
Test Point Breakout 7in (option) | Brk907 | Test Point | Pynckels:pad_0_8mm_1_5mm | Vero Loop Terminal 01x01 1.02mm
Test Point Breakout 7in (option) | Brk908 | Test Point | Pynckels:pad_0_8mm_1_5mm | Vero Loop Terminal 01x01 1.02mm
Test Point Breakout 7in (option) | Brk909 | Test Point | Pynckels:pad_0_8mm_1_5mm | Vero Loop Terminal 01x01 1.02mm
Test Point Breakout 7in (option) | Brk910 | Test Point | Pynckels:pad_0_8mm_1_5mm | Vero Loop Terminal 01x01 1.02mm
Test Point Breakout 7in (option) | Brk911 | Test Point | Pynckels:pad_0_8mm_1_5mm | Vero Loop Terminal 01x01 1.02mm
Test Point Breakout 7in (option) | Brk912 | Test Point | Pynckels:pad_0_8mm_1_5mm | Vero Loop Terminal 01x01 1.02mm
Test Point Breakout 7in (option) | Brk913 | Test Point | Pynckels:pad_0_8mm_1_5mm | Vero Loop Terminal 01x01 1.02mm
Test Point Breakout 7in (option) | Brk914 | Test Point | Pynckels:pad_0_8mm_1_5mm | Vero Loop Terminal 01x01 1.02mm
Test Point Breakout 7in (option) | Brk915 | Test Point | Pynckels:pad_0_8mm_1_5mm | Vero Loop Terminal 01x01 1.02mm
Test Point Breakout 7in (option) | Brk916 | Test Point | Pynckels:pad_0_8mm_1_5mm | Vero Loop Terminal 01x01 1.02mm
Test Point Breakout 7in (option) | Brk917 | Test Point | Pynckels:pad_0_8mm_1_5mm | Vero Loop Terminal 01x01 1.02mm
Test Point Breakout 7in (option) | Brk918 | Test Point | Pynckels:pad_0_8mm_1_5mm | Vero Loop Terminal 01x01 1.02mm
Test Point Breakout 7in (option) | Brk919 | Test Point | Pynckels:pad_0_8mm_1_5mm | Vero Loop Terminal 01x01 1.02mm
Test Point Breakout 7in (option) | Brk920 | Test Point | Pynckels:pad_0_8mm_1_5mm | Vero Loop Terminal 01x01 1.02mm
Test Point Breakout 7in (option) | Brk921 | Test Point | Pynckels:pad_0_8mm_1_5mm | Vero Loop Terminal 01x01 1.02mm
Test Point Breakout 7in (option) | Brk922 | Test Point | Pynckels:pad_0_8mm_1_5mm | Vero Loop Terminal 01x01 1.02mm
Test Point Breakout 7in (option) | Brk923 | Test Point | Pynckels:pad_0_8mm_1_5mm | Vero Loop Terminal 01x01 1.02mm
Test Point Breakout 7in (option) | Brk924 | Test Point | Pynckels:pad_0_8mm_1_5mm | Vero Loop Terminal 01x01 1.02mm
Test Point Breakout 7in (option) | Brk925 | Test Point | Pynckels:pad_0_8mm_1_5mm | Vero Loop Terminal 01x01 1.02mm
Test Point Breakout 7in (option) | Brk926 | Test Point | Pynckels:pad_0_8mm_1_5mm | Vero Loop Terminal 01x01 1.02mm
Test Point Breakout 7in (option) | Brk927 | Test Point | Pynckels:pad_0_8mm_1_5mm | Vero Loop Terminal 01x01 1.02mm
Test Point Breakout 7in (option) | Brk928 | Test Point | Pynckels:pad_0_8mm_1_5mm | Vero Loop Terminal 01x01 1.02mm
Test Point Breakout 7in (option) | Brk929 | Test Point | Pynckels:pad_0_8mm_1_5mm | Vero Loop Terminal 01x01 1.02mm
Test Point Breakout 7in (option) | Brk930 | Test Point | Pynckels:pad_0_8mm_1_5mm | Vero Loop Terminal 01x01 1.02mm
Test Point Breakout 7in (option) | Brk931 | Test Point | Pynckels:pad_0_8mm_1_5mm | Vero Loop Terminal 01x01 1.02mm
Test Point Breakout 7in (option) | Brk932 | Test Point | Pynckels:pad_0_8mm_1_5mm | Vero Loop Terminal 01x01 1.02mm
Test Point Breakout 7in (option) | Brk933 | Test Point | Pynckels:pad_0_8mm_1_5mm | Vero Loop Terminal 01x01 1.02mm
Test Point Breakout 7in (option) | Brk934 | Test Point | Pynckels:pad_0_8mm_1_5mm | Vero Loop Terminal 01x01 1.02mm
Test Point Breakout 7in (option) | Brk935 | Test Point | Pynckels:pad_0_8mm_1_5mm | Vero Loop Terminal 01x01 1.02mm
Test Point Breakout 7in (option) | Brk936 | Test Point | Pynckels:pad_0_8mm_1_5mm | Vero Loop Terminal 01x01 1.02mm
Test Point Breakout 7in (option) | Brk937 | Test Point | Pynckels:pad_0_8mm_1_5mm | Vero Loop Terminal 01x01 1.02mm
Test Point Breakout 7in (option) | Brk938 | Test Point | Pynckels:pad_0_8mm_1_5mm | Vero Loop Terminal 01x01 1.02mm
Test Point Breakout 7in (option) | Brk939 | Test Point | Pynckels:pad_0_8mm_1_5mm | Vero Loop Terminal 01x01 1.02mm
Test Point Breakout 7in (option) | Brk940 | Test Point | Pynckels:pad_0_8mm_1_5mm | Vero Loop Terminal 01x01 1.02mm
Test Point Breakout 7in (option) | Brk941 | Test Point | Pynckels:pad_0_8mm_1_5mm | Vero Loop Terminal 01x01 1.02mm
Test Point Breakout 7in (option) | Brk942 | Test Point | Pynckels:pad_0_8mm_1_5mm | Vero Loop Terminal 01x01 1.02mm
Test Point Breakout 7in (option) | Brk943 | Test Point | Pynckels:pad_0_8mm_1_5mm | Vero Loop Terminal 01x01 1.02mm
Test Point Breakout 7in (option) | Brk944 | Test Point | Pynckels:pad_0_8mm_1_5mm | Vero Loop Terminal 01x01 1.02mm
Test Point Breakout 7in (option) | Brk945 | Test Point | Pynckels:pad_0_8mm_1_5mm | Vero Loop Terminal 01x01 1.02mm
Test Point Breakout 7in (option) | Brk946 | Test Point | Pynckels:pad_0_8mm_1_5mm | Vero Loop Terminal 01x01 1.02mm
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

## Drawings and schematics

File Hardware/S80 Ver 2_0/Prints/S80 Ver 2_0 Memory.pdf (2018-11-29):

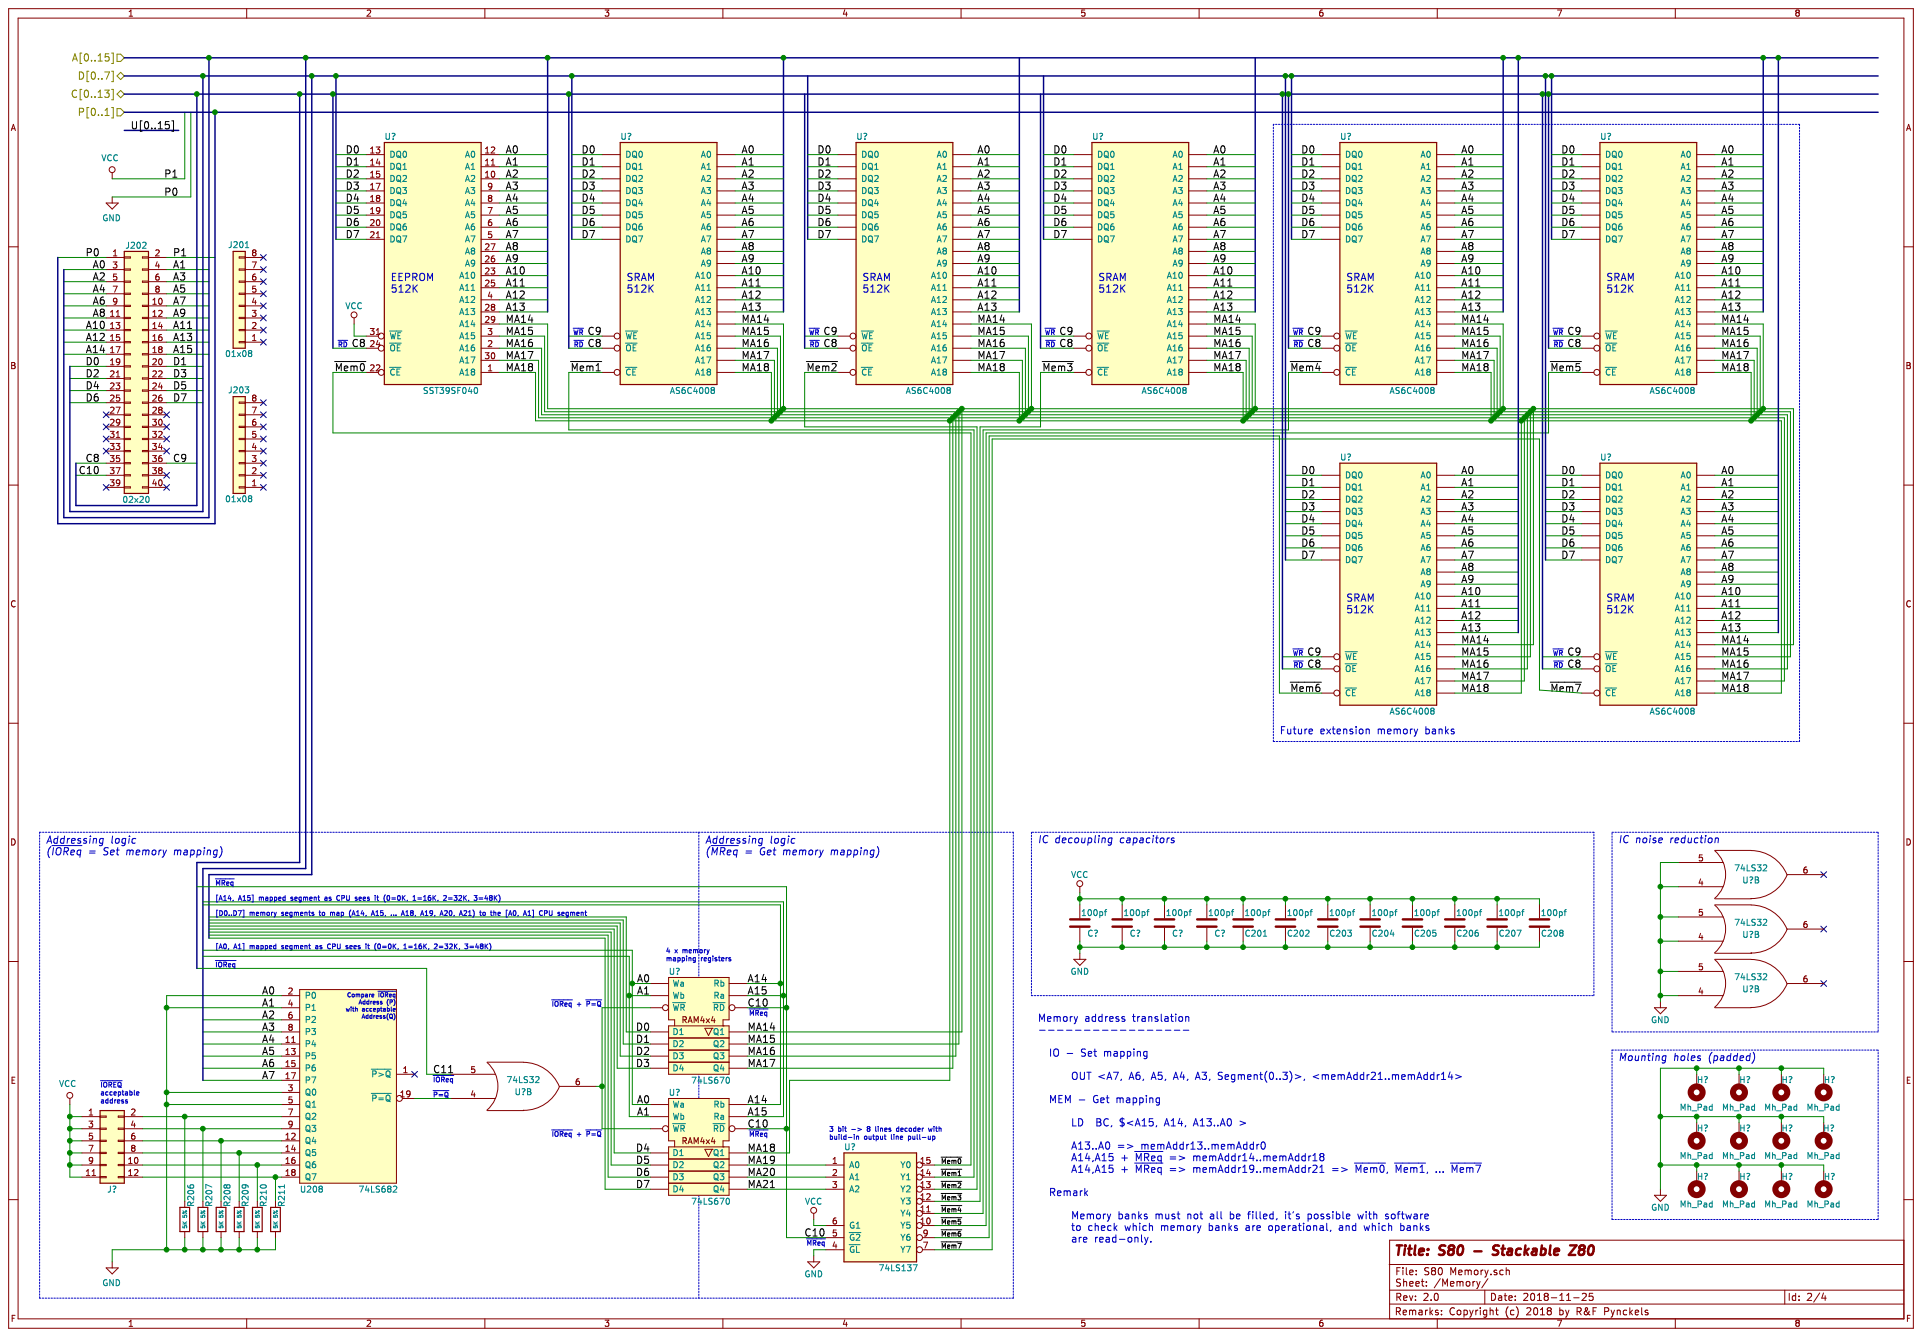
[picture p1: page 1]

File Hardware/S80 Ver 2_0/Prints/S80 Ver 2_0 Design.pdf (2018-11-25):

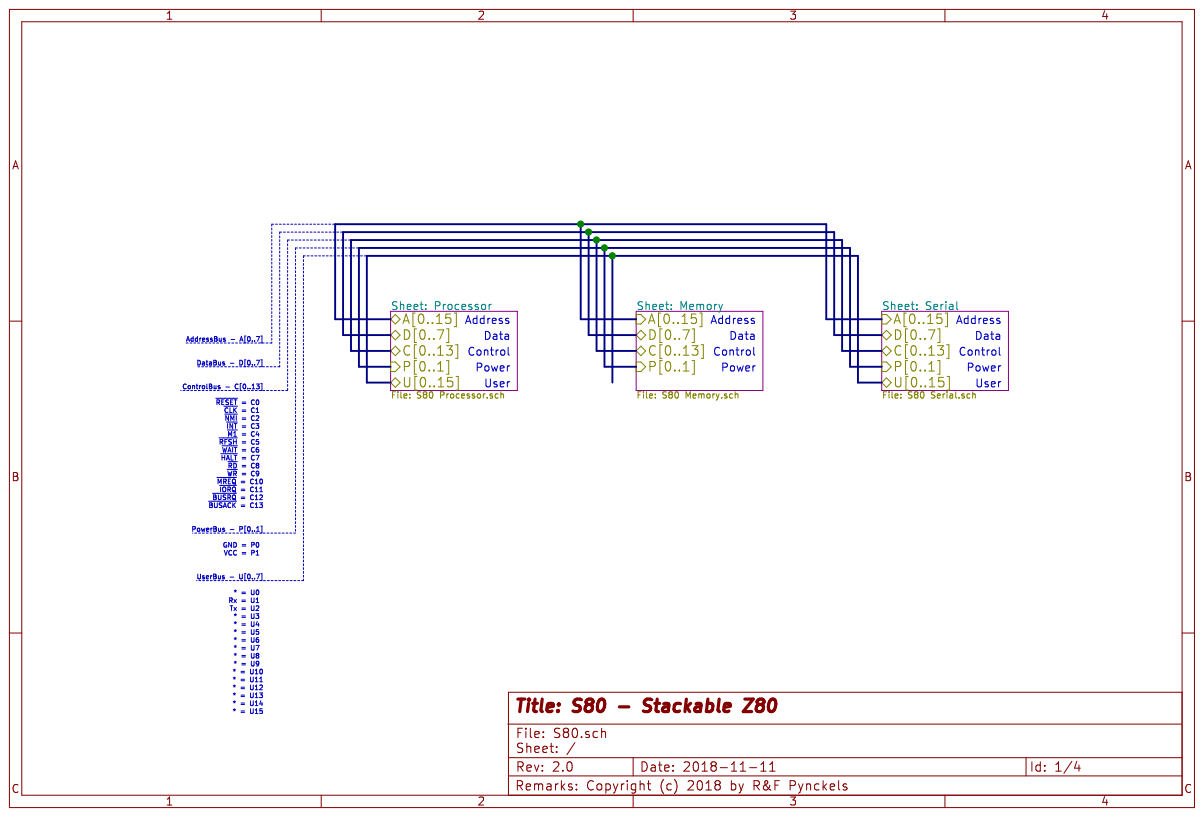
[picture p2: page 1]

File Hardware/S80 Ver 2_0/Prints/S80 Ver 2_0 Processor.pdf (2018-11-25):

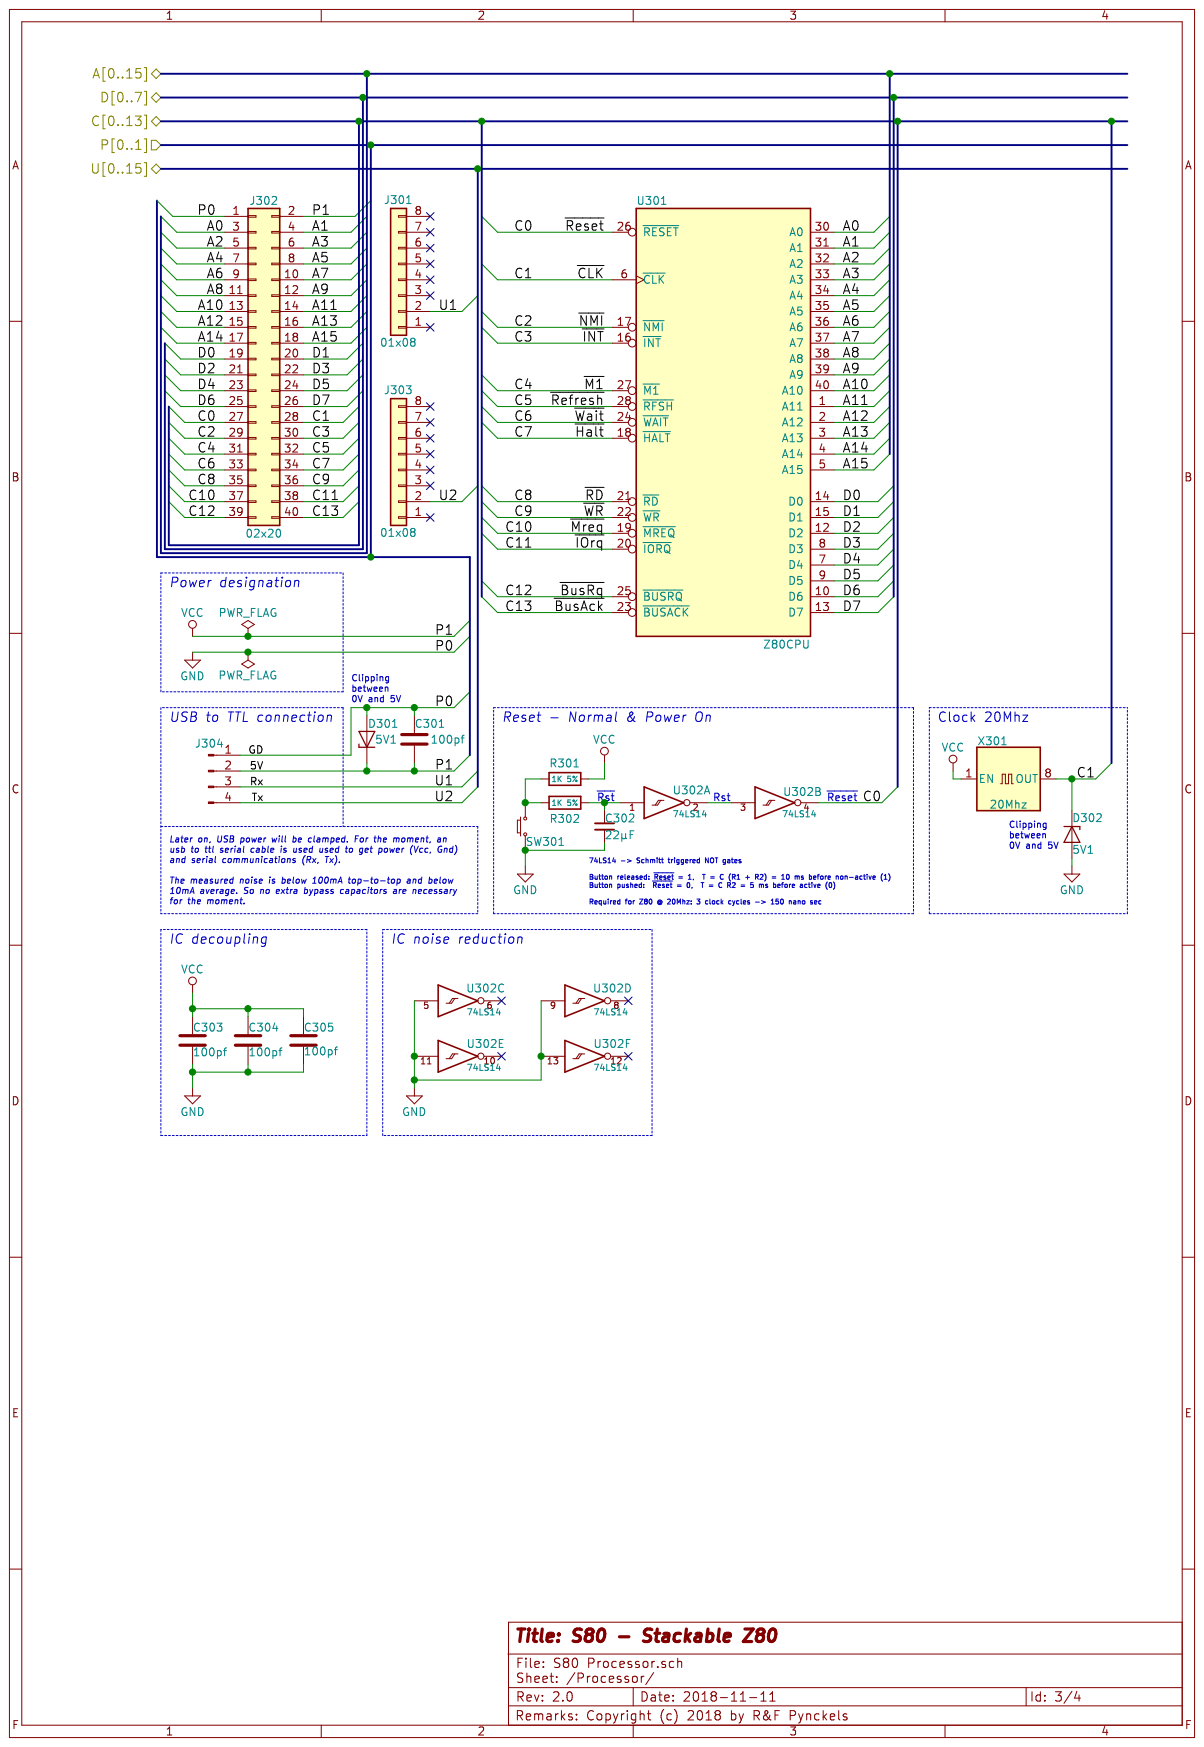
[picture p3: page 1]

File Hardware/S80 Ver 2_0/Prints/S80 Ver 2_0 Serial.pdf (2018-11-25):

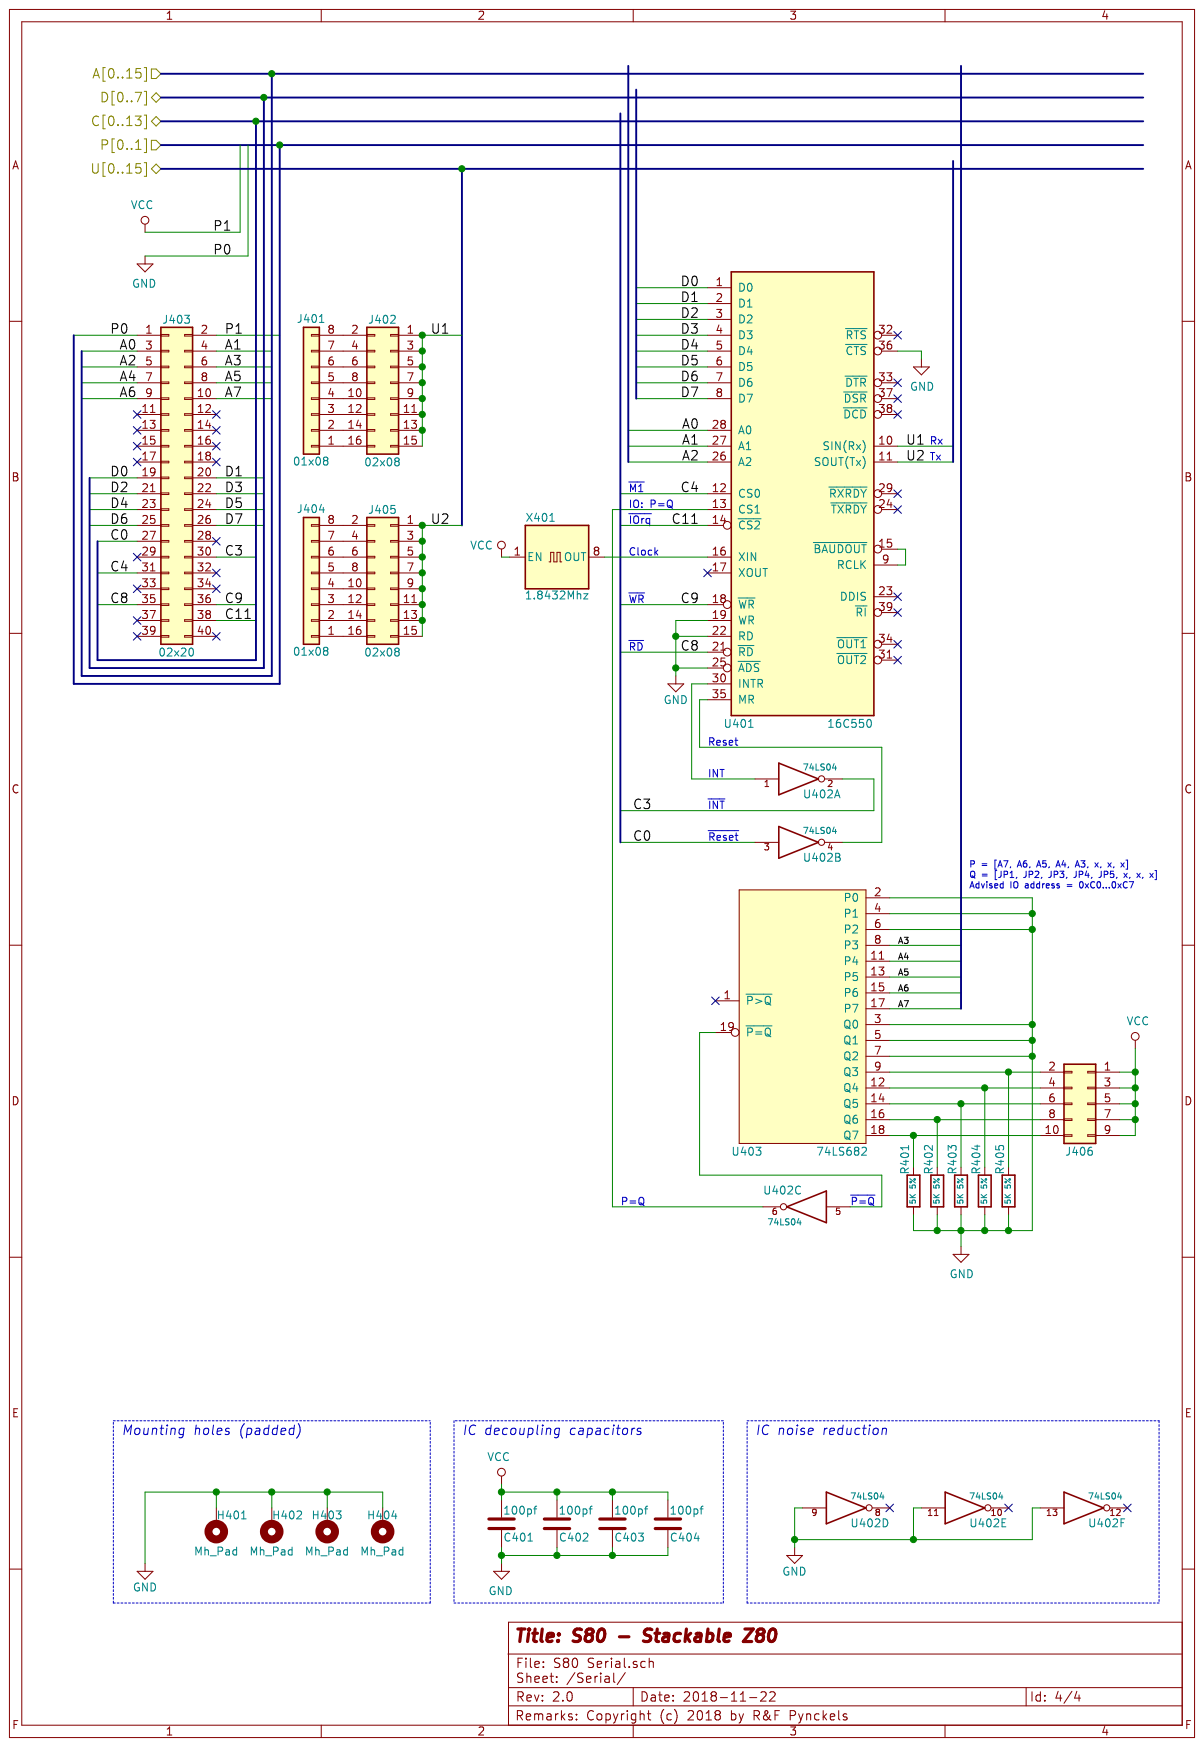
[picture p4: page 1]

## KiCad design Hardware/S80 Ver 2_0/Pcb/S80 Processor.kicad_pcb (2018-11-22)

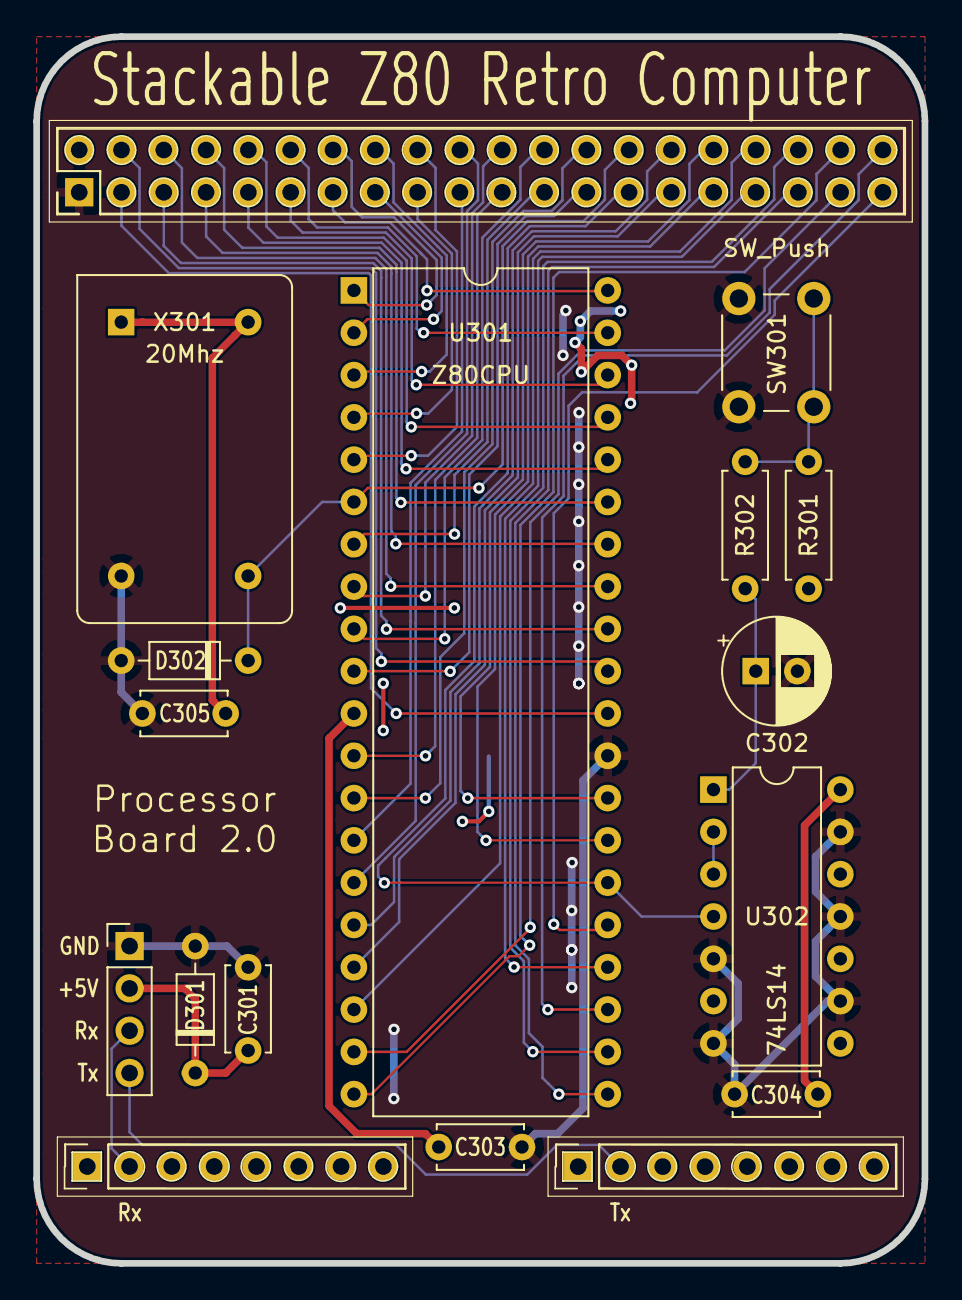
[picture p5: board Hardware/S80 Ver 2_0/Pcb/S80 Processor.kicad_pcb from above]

Board: 2 copper layers, 53.3 x 73.7 mm, 17 parts (0 on the bottom side), 45 nets.

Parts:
C301, C303, C304, C305: 100pf; C_Disc_D5.0mm_W2.5mm_P5.00mm
C302: 22μF; CP_Radial_D6.3mm_P2.50mm
D301, D302: 5V1; D_Zener_Reverse_Biased
J301, J303: 01x08; PinSocket_1x08_P2.54mm_Vertical
J302: 02x20; PinSocket_2x20_P2.54mm_Vertical
J304: 01x04; PinHeader_1x04_P2.54mm_Vertical
R301, R302: 1K 5%; R_Axial_DIN0207_L6.3mm_D2.5mm_P7.62mm_Horizontal
SW301: SW_Push; SW_PUSH_6mm
U301: Z80CPU; DIP-40_W15.24mm
U302: 74LS14; DIP-14_W7.62mm
X301: 20Mhz; Oscillator_DIP-14

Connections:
/Memory/A0: J302.3, U301.30
/Memory/A1: J302.4, U301.31
/Memory/A2: J302.5, U301.32
/Memory/A3: J302.6, U301.33
/Memory/A4: J302.7, U301.34
/Memory/A5: J302.8, U301.35
/Memory/A6: J302.9, U301.36
/Memory/A7: J302.10, U301.37
/Memory/A8: J302.11, U301.38
/Memory/A9: J302.12, U301.39
/Memory/A10: J302.13, U301.40
/Memory/A11: J302.14, U301.1
/Memory/A12: J302.15, U301.2
/Memory/A13: J302.16, U301.3
/Memory/A14: J302.17, U301.4
/Memory/A15: J302.18, U301.5
/Memory/C8: J302.35, U301.21
/Memory/C9: J302.36, U301.22
/Memory/C10: J302.37, U301.19
/Memory/D0: J302.19, U301.14
/Memory/D1: J302.20, U301.15
/Memory/D2: J302.21, U301.12
/Memory/D3: J302.22, U301.8
/Memory/D4: J302.23, U301.7
/Memory/D5: J302.24, U301.9
/Memory/D6: J302.25, U301.10
/Memory/D7: J302.26, U301.13
/Processor/C0: J302.27, U301.26, U302.4
/Processor/C1: D302.2, J302.28, U301.6, X301.8
/Processor/C2: J302.29, U301.17
/Processor/C3: J302.30, U301.16
/Processor/C4: J302.31, U301.27
/Processor/C5: J302.32, U301.28
/Processor/C6: J302.33, U301.24
/Processor/C7: J302.34, U301.18
/Processor/C11: J302.38, U301.20
/Processor/C12: J302.39, U301.25
/Processor/C13: J302.40, U301.23
/Processor/Rx: J301.2, J304.3
/Processor/Tx: J303.2, J304.4
GND: C301.1, C302.2, C303.1, C304.1, C305.1, D301.1, D302.1, J302.1, J304.1, SW301.1, U301.29, U302.5, U302.7, U302.9, U302.11, U302.13, X301.7
unnamed: C302.1, R302.1, U302.1
unnamed: R301.2, R302.2, SW301.2
unnamed: U302.2, U302.3
VCC: C301.2, C303.2, C304.2, C305.2, D301.2, J302.2, J304.2, R301.1, U301.11, U302.14, X301.1, X301.14

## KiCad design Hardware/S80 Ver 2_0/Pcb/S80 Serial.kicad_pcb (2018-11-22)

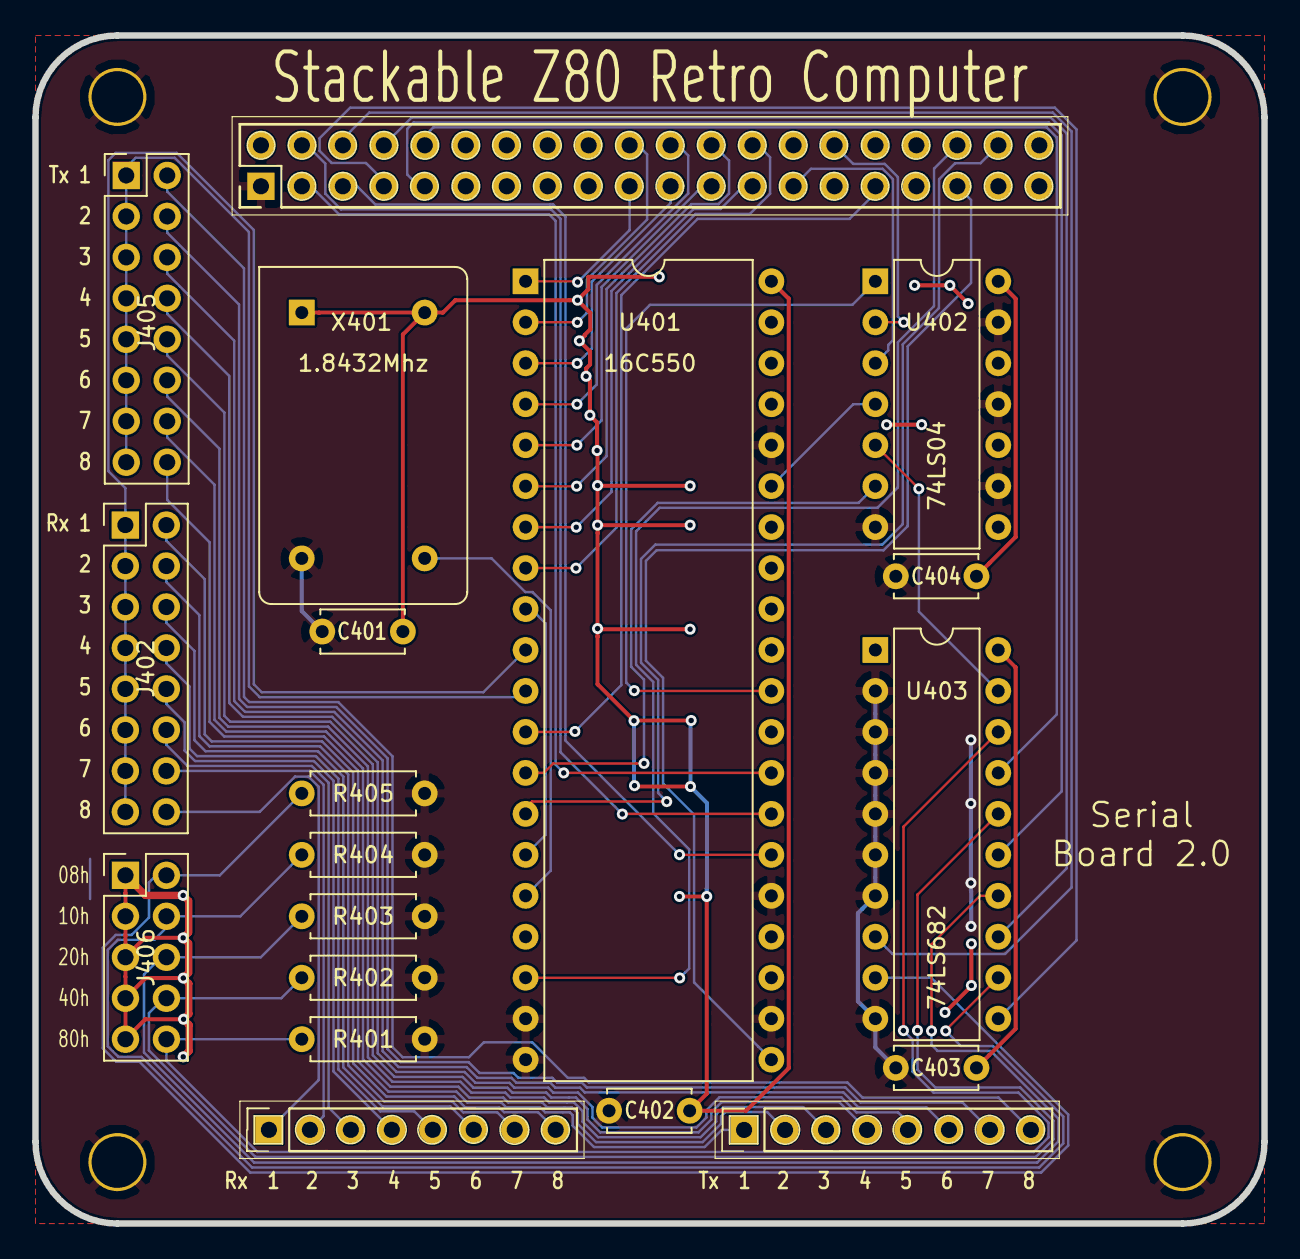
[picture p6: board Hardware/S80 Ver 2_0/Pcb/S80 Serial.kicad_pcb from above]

Board: 2 copper layers, 76.2 x 73.7 mm, 23 parts (0 on the bottom side), 53 nets.

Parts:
C401, C402, C403, C404: 100pf; C_Disc_D5.0mm_W2.5mm_P5.00mm
H401, H402, H403, H404: Mh_Pad; MountingHole_3.2mm_Via
J401, J404: 01x08; PinSocket_1x08_P2.54mm_Vertical
J402, J405: 02x08; PinHeader_2x08_P2.54mm_Vertical
J403: 02x20; PinSocket_2x20_P2.54mm_Vertical
J406: 02x05; PinHeader_2x05_P2.54mm_Vertical
R401, R402, R403, R404, R405: 5K 5%; R_Axial_DIN0207_L6.3mm_D2.5mm_P7.62mm_Horizontal
U401: 16C550; DIP-40_W15.24mm
U402: 74LS04; DIP-14_W7.62mm
U403: 74LS682; DIP-20_W7.62mm
X401: 1.8432Mhz; Oscillator_DIP-14

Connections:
/Memory/A0: J403.3, U401.28
/Memory/A1: J403.4, U401.27
/Memory/A2: J403.5, U401.26
/Memory/A3: J403.6, U403.8
/Memory/A4: J403.7, U403.11
/Memory/A5: J403.8, U403.13
/Memory/A6: J403.9, U403.15
/Memory/A7: J403.10, U403.17
/Memory/C8: J403.35, U401.21
/Memory/C9: J403.36, U401.18
/Memory/D0: J403.19, U401.1
/Memory/D1: J403.20, U401.2
/Memory/D2: J403.21, U401.3
/Memory/D3: J403.22, U401.4
/Memory/D4: J403.23, U401.5
/Memory/D5: J403.24, U401.6
/Memory/D6: J403.25, U401.7
/Memory/D7: J403.26, U401.8
/Processor/C0: J403.27, U402.3
/Processor/C3: J403.30, U402.2
/Processor/C4: J403.31, U401.12
/Processor/C11: J403.38, U401.14
/Processor/Rx: J402.1, J402.3, J402.5, J402.7, J402.9, J402.11, J402.13, J402.15, U401.10
/Processor/Tx: J405.1, J405.3, J405.5, J405.7, J405.9, J405.11, J405.13, J405.15, U401.11
GND: C401.1, C402.1, C403.1, C404.1, H401.1, H402.1, H403.1, H404.1, J403.1, R401.2, R402.2, R403.2, R404.2, R405.2, U401.19, U401.20, U401.22, U401.25, U401.36, U402.7, U402.9, U402.11, U402.13, U403.2, U403.3, U403.4, U403.5, U403.6, U403.7, U403.10, X401.7
unnamed: J401.1, J402.16
unnamed: J401.2, J402.14
unnamed: J401.3, J402.12
unnamed: J401.4, J402.10
unnamed: J401.5, J402.8
unnamed: J401.6, J402.6
unnamed: J401.7, J402.4
unnamed: J401.8, J402.2
unnamed: J404.1, J405.16
unnamed: J404.2, J405.14
unnamed: J404.3, J405.12
unnamed: J404.4, J405.10
unnamed: J404.5, J405.8
unnamed: J404.6, J405.6
unnamed: J404.7, J405.4
unnamed: J404.8, J405.2
unnamed: J406.2, R405.1, U403.9
unnamed: J406.4, R404.1, U403.12
unnamed: J406.6, R403.1, U403.14
unnamed: J406.8, R402.1, U403.16
unnamed: J406.10, R401.1, U403.18
unnamed: U401.13, U402.6
unnamed: U401.9, U401.15
unnamed: U401.16, X401.8
unnamed: U401.30, U402.1
unnamed: U401.35, U402.4
unnamed: U402.5, U403.19
VCC: C401.2, C402.2, C403.2, C404.2, J403.2, J406.1, J406.3, J406.5, J406.7, J406.9, U401.40, U402.14, U403.20, X401.1, X401.14

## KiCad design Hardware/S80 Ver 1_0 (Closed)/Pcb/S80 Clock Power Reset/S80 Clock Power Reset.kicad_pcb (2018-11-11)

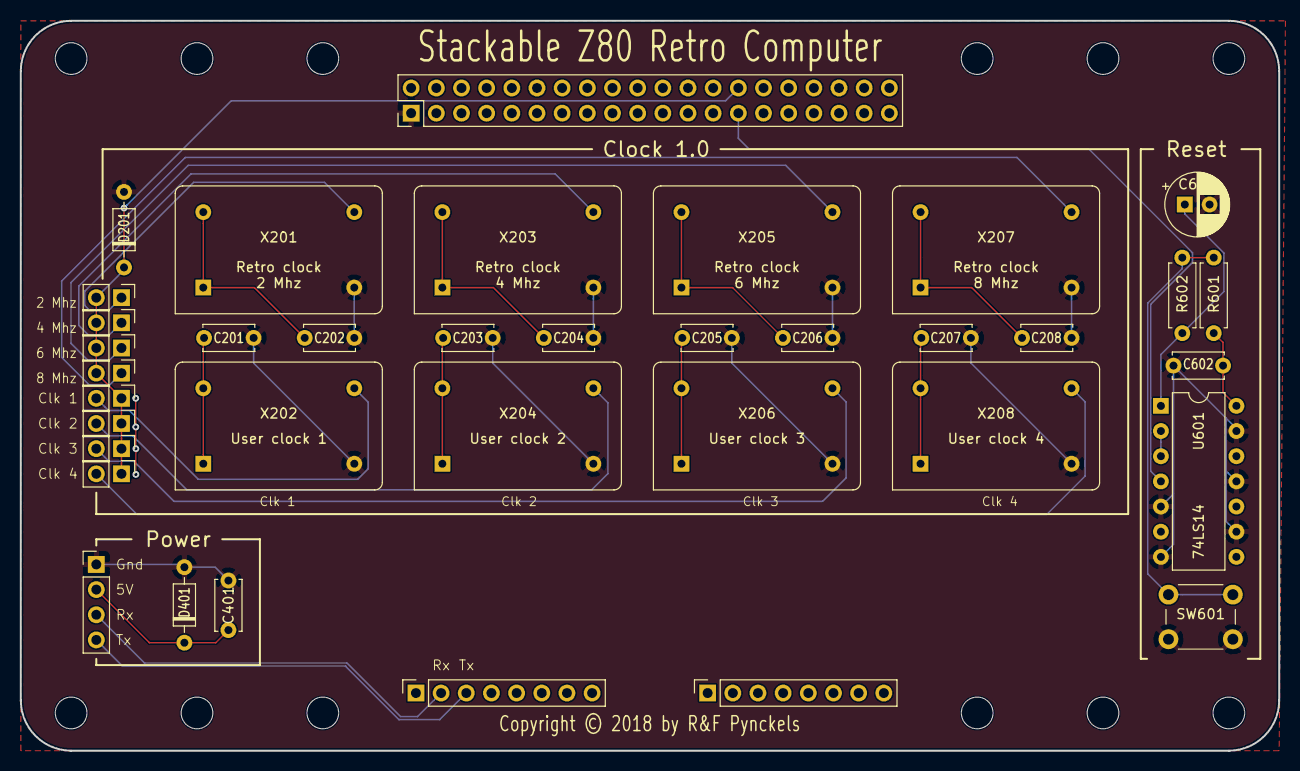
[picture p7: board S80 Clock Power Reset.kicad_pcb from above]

Board: 2 copper layers, 127.0 x 73.7 mm, 37 parts (0 on the bottom side), 17 nets.

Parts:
C201, C202, C203, C204, C205, C206, C207, C208, C401, C602: 100pf; C_Disc_D5.0mm_W2.5mm_P5.00mm
C601: 22μF; CP_Radial_D6.3mm_P2.50mm
D201, D401: 5V1; D_Zener_Reverse_Biased
J201: 02x20; PinSocket_2x20_P2.54mm_Vertical
J402, J403: 01x08; PinSocket_1x08_P2.54mm_Vertical
J404: 01x04; PinHeader_1x04_P2.54mm_Vertical
JP201, JP202, JP203, JP204, JP205, JP206, JP207, JP208: 01x02; PinHeader_1x02_P2.54mm_Vertical
R601, R602: 1K; R_Axial_DIN0207_L6.3mm_D2.5mm_P7.62mm_Horizontal
SW601: SW_Push; SW_PUSH_6mm
U601: 74LS14; DIP-14_W7.62mm
X201: 2.5Mhz; Oscillator_DIP-14
X202: User clk 1; Oscillator_DIP-14
X203: 4Mhz; Oscillator_DIP-14
X204: User clk 2; Oscillator_DIP-14
X205: 6Mhz; Oscillator_DIP-14
X206: User clk 3; Oscillator_DIP-14
X207: 8Mhz; Oscillator_DIP-14
X208: User clk 4; Oscillator_DIP-14

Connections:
/Breakout 2in/C0: J201.27, U601.4
/Breakout 2in/C1: D201.2, J201.28, JP201.2, JP202.1, JP203.2, JP204.1, JP205.2, JP206.1, JP207.2, JP208.1
/Power/Rx: J402.2, J404.3
/Power/Tx: J402.3, J404.4
GND: C201.1, C202.1, C203.1, C204.1, C205.1, C206.1, C207.1, C208.1, C401.1, C601.2, C602.1, D201.1, D401.1, J201.1, J404.1, SW601.1, U601.5, U601.7, U601.9, U601.11, U601.13, X201.7, X202.7, X203.7, X204.7, X205.7, X206.7, X207.7, X208.7
unnamed: C601.1, R602.1, U601.1
unnamed: JP201.1, X201.8
unnamed: JP202.2, X202.8
unnamed: JP203.1, X203.8
unnamed: JP204.2, X204.8
unnamed: JP205.1, X205.8
unnamed: JP206.2, X206.8
unnamed: JP207.1, X207.8
unnamed: JP208.2, X208.8
unnamed: R601.2, R602.2, SW601.2
unnamed: U601.2, U601.3
VCC: C201.2, C202.2, C203.2, C204.2, C205.2, C206.2, C207.2, C208.2, C401.2, C602.2, D401.2, J201.2, J404.2, R601.1, U601.14, X201.1, X201.14, X202.1, X202.14, X203.1, X203.14, X204.1, X204.14, X205.1, X205.14, X206.1, X206.14, X207.1, X207.14, X208.1, X208.14

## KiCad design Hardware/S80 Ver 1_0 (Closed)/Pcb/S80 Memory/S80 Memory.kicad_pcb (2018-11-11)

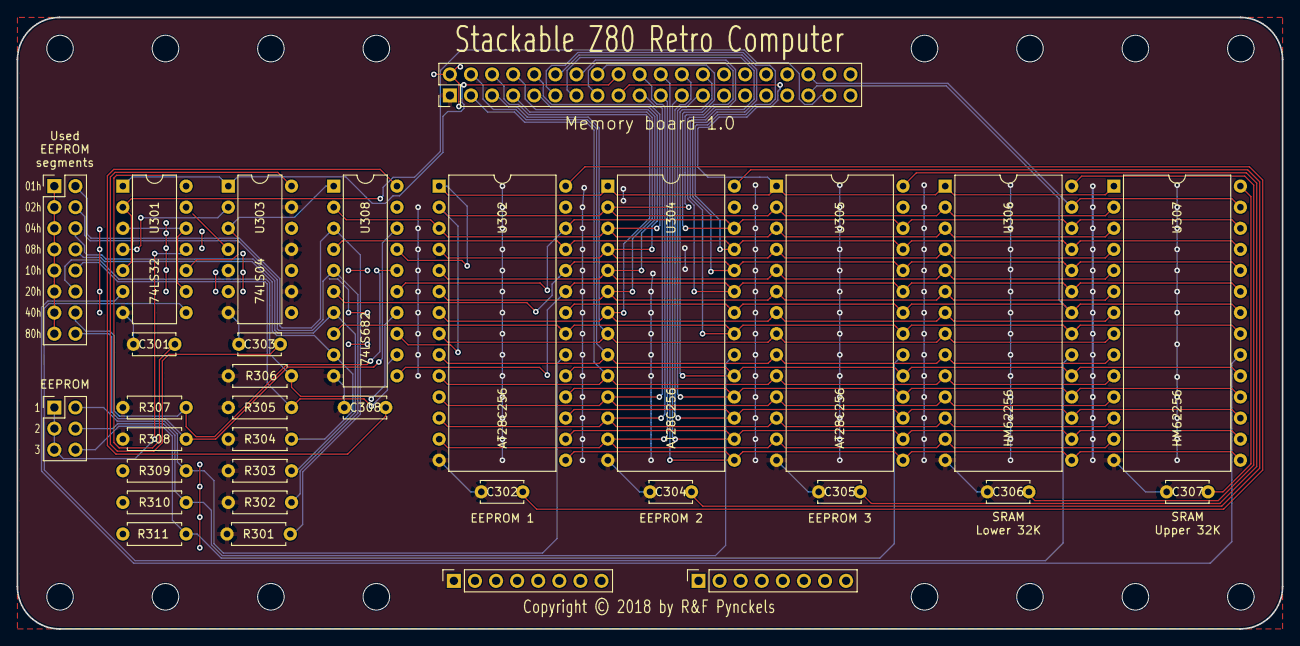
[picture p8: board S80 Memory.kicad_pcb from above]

Board: 2 copper layers, 152.4 x 73.7 mm, 32 parts (0 on the bottom side), 47 nets.

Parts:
C301, C302, C303, C304, C305, C306, C307, C308: 100pf; C_Disc_D5.0mm_W2.5mm_P5.00mm
J301: 02x20; PinSocket_2x20_P2.54mm_Vertical
J302, J303: 01x08; PinSocket_1x08_P2.54mm_Vertical
J304: 02x08; PinHeader_2x08_P2.54mm_Vertical
J305: 02x03; PinHeader_2x03_P2.54mm_Vertical
R301, R302, R303, R304, R305, R306, R307, R308: 220 5%; R_Axial_DIN0207_L6.3mm_D2.5mm_P7.62mm_Horizontal
R309, R310, R311: 5K 1%; R_Axial_DIN0207_L6.3mm_D2.5mm_P7.62mm_Horizontal
U301: 74LS32; DIP-14_W7.62mm
U302, U304, U305: AT28C256; DIP-28_W15.24mm
U303: 74LS04; DIP-14_W7.62mm
U306, U307: HM62256; DIP-28_W15.24mm
U308: 74LS682; DIP-20_W7.62mm

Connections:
/Breakout 2in/A0: J301.3, U302.10, U304.10, U305.10, U306.10, U307.10
/Breakout 2in/A1: J301.4, U302.9, U304.9, U305.9, U306.9, U307.9
/Breakout 2in/A2: J301.5, U302.8, U304.8, U305.8, U306.8, U307.8
/Breakout 2in/A3: J301.6, U302.7, U304.7, U305.7, U306.7, U307.7
/Breakout 2in/A4: J301.7, U302.6, U304.6, U305.6, U306.6, U307.6
/Breakout 2in/A5: J301.8, U302.5, U304.5, U305.5, U306.5, U307.5
/Breakout 2in/A6: J301.9, U302.4, U304.4, U305.4, U306.4, U307.4
/Breakout 2in/A7: J301.10, U302.3, U304.3, U305.3, U306.3, U307.3, U308.2
/Breakout 2in/A8: J301.11, U302.25, U304.25, U305.25, U306.25, U307.25, U308.4
/Breakout 2in/A9: J301.12, U302.24, U304.24, U305.24, U306.24, U307.24, U308.6
/Breakout 2in/A10: J301.13, U302.21, U304.21, U305.21, U306.21, U307.21, U308.8
/Breakout 2in/A11: J301.14, U302.23, U304.23, U305.23, U306.23, U307.23, U308.11
/Breakout 2in/A12: J301.15, U302.2, U304.2, U305.2, U306.2, U307.2, U308.13
/Breakout 2in/A13: J301.16, U302.26, U304.26, U305.26, U306.26, U307.26, U308.15
/Breakout 2in/A14: J301.17, U302.1, U304.1, U305.1, U306.1, U307.1, U308.17
/Breakout 2in/A15: J301.18, U301.1, U303.1
/Breakout 2in/C8: J301.35, U302.22, U304.22, U305.22, U306.22, U307.22
/Breakout 2in/C9: J301.36, U306.27, U307.27
/Breakout 2in/C10: J301.37, U301.2, U301.5
/Breakout 2in/D0: J301.19, U302.11, U304.11, U305.11, U306.11, U307.11
/Breakout 2in/D1: J301.20, U302.12, U304.12, U305.12, U306.12, U307.12
/Breakout 2in/D2: J301.21, U302.13, U304.13, U305.13, U306.13, U307.13
/Breakout 2in/D3: J301.22, U302.15, U304.15, U305.15, U306.15, U307.15
/Breakout 2in/D4: J301.23, U302.16, U304.16, U305.16, U306.16, U307.16
/Breakout 2in/D5: J301.24, U302.17, U304.17, U305.17, U306.17, U307.17
/Breakout 2in/D6: J301.25, U302.18, U304.18, U305.18, U306.18, U307.18
/Breakout 2in/D7: J301.26, U302.19, U304.19, U305.19, U306.19, U307.19
/Memory/~A15: U301.4, U303.2
/Memory/~EpL0~: J305.2, R309.2, U302.20
/Memory/~EpL1~: J305.4, R310.2, U304.20
/Memory/~EpL2~: J305.6, R311.2, U305.20
/Memory/~EpL~: J305.1, J305.3, J305.5, U301.11
/Memory/~RaL~: U301.8, U306.20
/Memory/~RaU~: U301.6, U307.20
GND: C301.1, C302.1, C303.1, C304.1, C305.1, C306.1, C307.1, C308.1, J301.1, R301.2, R302.2, R303.2, R304.2, R305.2, R306.2, R307.2, R308.2, U301.7, U302.14, U303.5, U303.7, U303.9, U303.11, U303.13, U304.14, U305.14, U306.14, U307.14, U308.10
unnamed: J304.2, R301.1, U308.3
unnamed: J304.4, R302.1, U308.5
unnamed: J304.6, R303.1, U308.7
unnamed: J304.8, R304.1, U308.9
unnamed: J304.10, R305.1, U308.12
unnamed: J304.12, R306.1, U308.14
unnamed: J304.14, R307.1, U308.16
unnamed: J304.16, R308.1, U308.18
unnamed: U301.10, U303.3, U308.1
unnamed: U301.3, U301.9, U301.12
unnamed: U301.13, U303.4
VCC: C301.2, C302.2, C303.2, C304.2, C305.2, C306.2, C307.2, C308.2, J301.2, J304.1, J304.3, J304.5, J304.7, J304.9, J304.11, J304.13, J304.15, R309.1, R310.1, R311.1, U301.14, U302.27, U302.28, U303.14, U304.27, U304.28, U305.27, U305.28, U306.28, U307.28, U308.20

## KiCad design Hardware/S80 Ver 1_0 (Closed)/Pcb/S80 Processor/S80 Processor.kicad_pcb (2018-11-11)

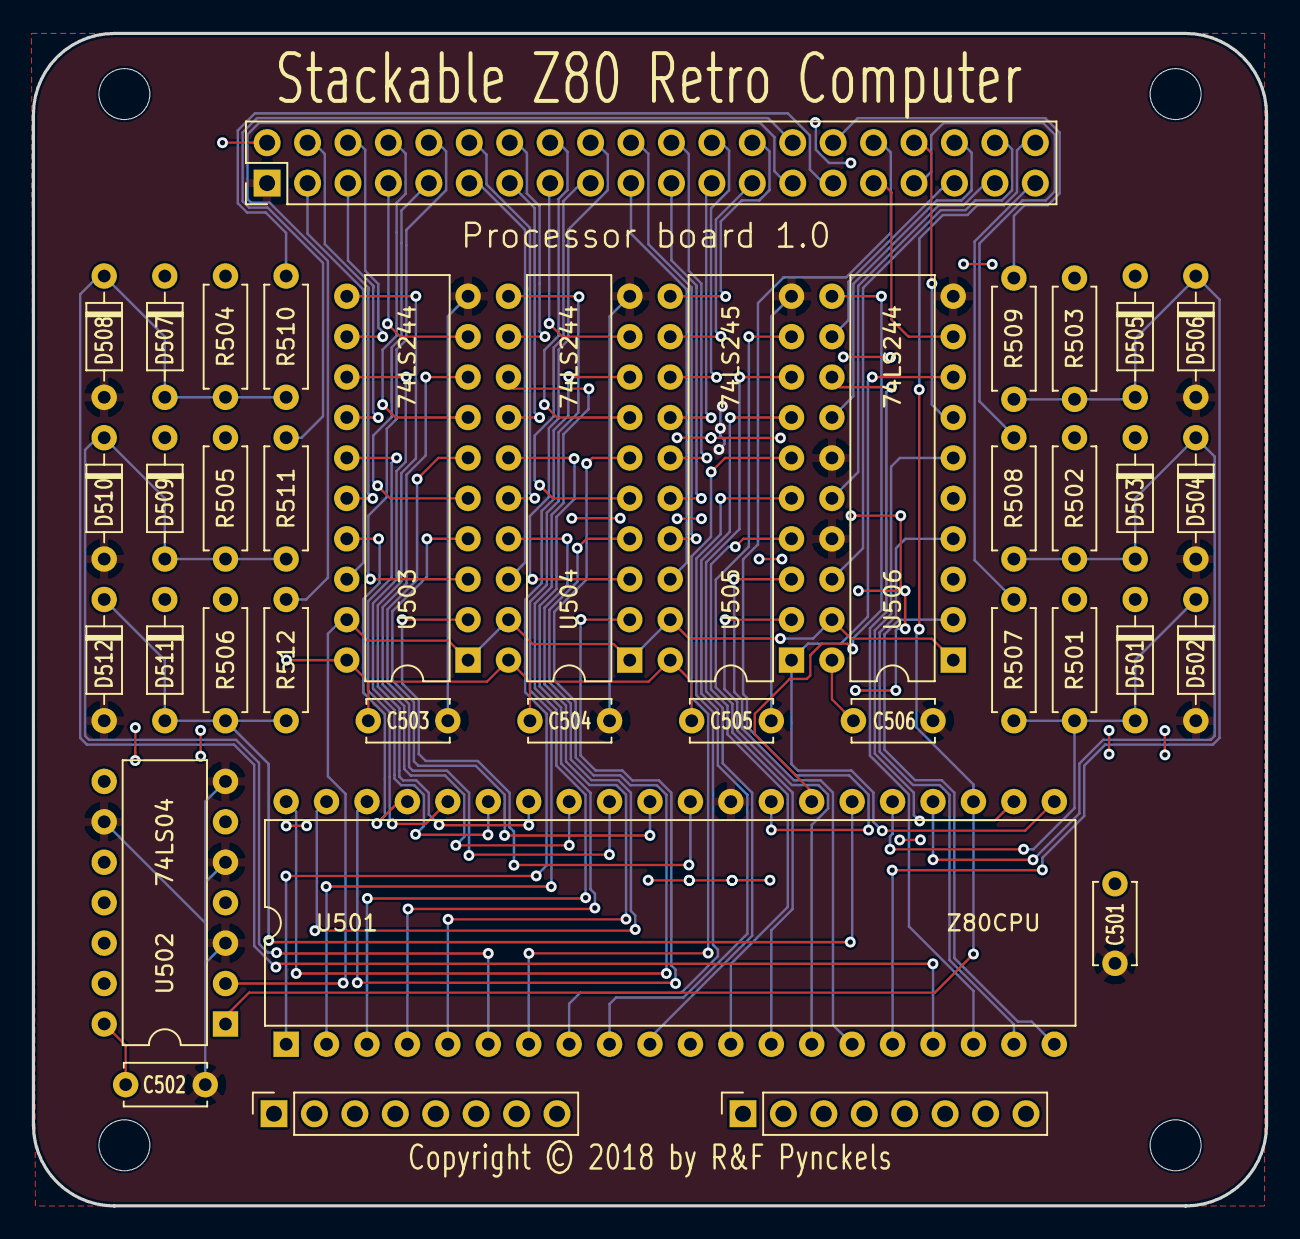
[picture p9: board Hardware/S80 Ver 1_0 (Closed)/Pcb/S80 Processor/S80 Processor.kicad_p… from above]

Board: 2 copper layers, 77.5 x 73.7 mm, 39 parts (0 on the bottom side), 77 nets.

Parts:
C501, C502, C503, C504, C505, C506: 100pf; C_Disc_D5.0mm_W2.5mm_P5.00mm
D501, D502, D503, D504, D505, D506, D507, D508, D509, D510, D511, D512: D; D_1N4148_Reverse_Biased
J501: 02x20; PinSocket_2x20_P2.54mm_Vertical
J502, J503: 01x08; PinSocket_1x08_P2.54mm_Vertical
R501, R502, R503, R504, R505, R506: 1K; R_Axial_DIN0207_L6.3mm_D2.5mm_P7.62mm_Horizontal
R507, R508, R509, R510, R511, R512: 220; R_Axial_DIN0207_L6.3mm_D2.5mm_P7.62mm_Horizontal
U501: Z80CPU; DIP-40_W15.24mm
U502: 74LS04; DIP-14_W7.62mm
U503, U504, U506: 74LS244; DIP-20_W7.62mm
U505: 74LS245; DIP-20_W7.62mm

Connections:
/Breakout 2in/A0: J501.3, U503.18
/Breakout 2in/A1: J501.4, U503.16
/Breakout 2in/A2: J501.5, U503.14
/Breakout 2in/A3: J501.6, U503.12
/Breakout 2in/A4: J501.7, U503.9
/Breakout 2in/A5: J501.8, U503.7
/Breakout 2in/A6: J501.9, U503.5
/Breakout 2in/A7: J501.10, U503.3
/Breakout 2in/A8: J501.11, U504.18
/Breakout 2in/A9: J501.12, U504.16
/Breakout 2in/A10: J501.13, U504.14
/Breakout 2in/A11: J501.14, U504.12
/Breakout 2in/A12: J501.15, U504.9
/Breakout 2in/A13: J501.16, U504.7
/Breakout 2in/A14: J501.17, U504.5
/Breakout 2in/A15: J501.18, U504.3
/Breakout 2in/C0: J501.27, R512.1
/Breakout 2in/C1: J501.28, R511.1
/Breakout 2in/C2: J501.29, R510.1
/Breakout 2in/C3: J501.30, R509.1
/Breakout 2in/C4: J501.31, U506.9
/Breakout 2in/C5: J501.32, U501.28
/Breakout 2in/C6: J501.33, R508.1
/Breakout 2in/C7: J501.34, U506.7
/Breakout 2in/C8: J501.35, U506.12
/Breakout 2in/C9: J501.36, U506.14
/Breakout 2in/C10: J501.37, U506.16
/Breakout 2in/C11: J501.38, U506.18
/Breakout 2in/C12: J501.39, R507.1
/Breakout 2in/C13: J501.40, U501.23, U502.1
/Breakout 2in/D0: J501.19, U505.18
/Breakout 2in/D1: J501.20, U505.17
/Breakout 2in/D2: J501.21, U505.16
/Breakout 2in/D3: J501.22, U505.15
/Breakout 2in/D4: J501.23, U505.14
/Breakout 2in/D5: J501.24, U505.13
/Breakout 2in/D6: J501.25, U505.12
/Breakout 2in/D7: J501.26, U505.11
/Processor/Out: U502.2, U503.1, U503.19, U504.1, U504.19, U505.19, U506.1, U506.19
/Processor/ZA0: U501.30, U503.2
/Processor/ZA1: U501.31, U503.4
/Processor/ZA2: U501.32, U503.6
/Processor/ZA3: U501.33, U503.8
/Processor/ZA4: U501.34, U503.11
/Processor/ZA5: U501.35, U503.13
/Processor/ZA6: U501.36, U503.15
/Processor/ZA7: U501.37, U503.17
/Processor/ZA8: U501.38, U504.2
/Processor/ZA9: U501.39, U504.4
/Processor/ZA10: U501.40, U504.6
/Processor/ZA11: U501.1, U504.8
/Processor/ZA12: U501.2, U504.11
/Processor/ZA13: U501.3, U504.13
/Processor/ZA14: U501.4, U504.15
/Processor/ZA15: U501.5, U504.17
/Processor/ZD0: U501.14, U505.2
/Processor/ZD1: U501.15, U505.3
/Processor/ZD2: U501.12, U505.4
/Processor/ZD3: U501.8, U505.5
/Processor/ZD4: U501.7, U505.6
/Processor/ZD5: U501.9, U505.7
/Processor/ZD6: U501.10, U505.8
/Processor/ZD7: U501.13, U505.9
/Processor/~BusRq: D501.1, D502.2, R501.2, R507.2, U501.25
/Processor/~CLK: D509.1, D510.2, R505.2, R511.2, U501.6
/Processor/~Halt: U501.18, U506.13
/Processor/~INT: D505.1, D506.2, R503.2, R509.2, U501.16
/Processor/~IOrq: U501.20, U506.2
/Processor/~M1: U501.27, U506.11
/Processor/~Mreq: U501.19, U506.4
/Processor/~NMI: D507.1, D508.2, R504.2, R510.2, U501.17
/Processor/~RD: U501.21, U505.1, U506.8
/Processor/~Reset: D511.1, D512.2, R506.2, R512.2, U501.26
/Processor/~WR: U501.22, U506.6
/Processor/~Wait: D503.1, D504.2, R502.2, R508.2, U501.24
GND: C501.1, C502.1, C503.1, C504.1, C505.1, C506.1, D502.1, D504.1, D506.1, D508.1, D510.1, D512.1, J501.1, U501.29, U502.3, U502.5, U502.7, U502.9, U503.10, U504.10, U505.10, U506.10, U506.15, U506.17
VCC: C501.2, C502.2, C503.2, C504.2, C505.2, C506.2, D501.2, D503.2, D505.2, D507.2, D509.2, D511.2, J501.2, R501.1, R502.1, R503.1, R504.1, R505.1, R506.1, U501.11, U502.14, U503.20, U504.20, U505.20, U506.20

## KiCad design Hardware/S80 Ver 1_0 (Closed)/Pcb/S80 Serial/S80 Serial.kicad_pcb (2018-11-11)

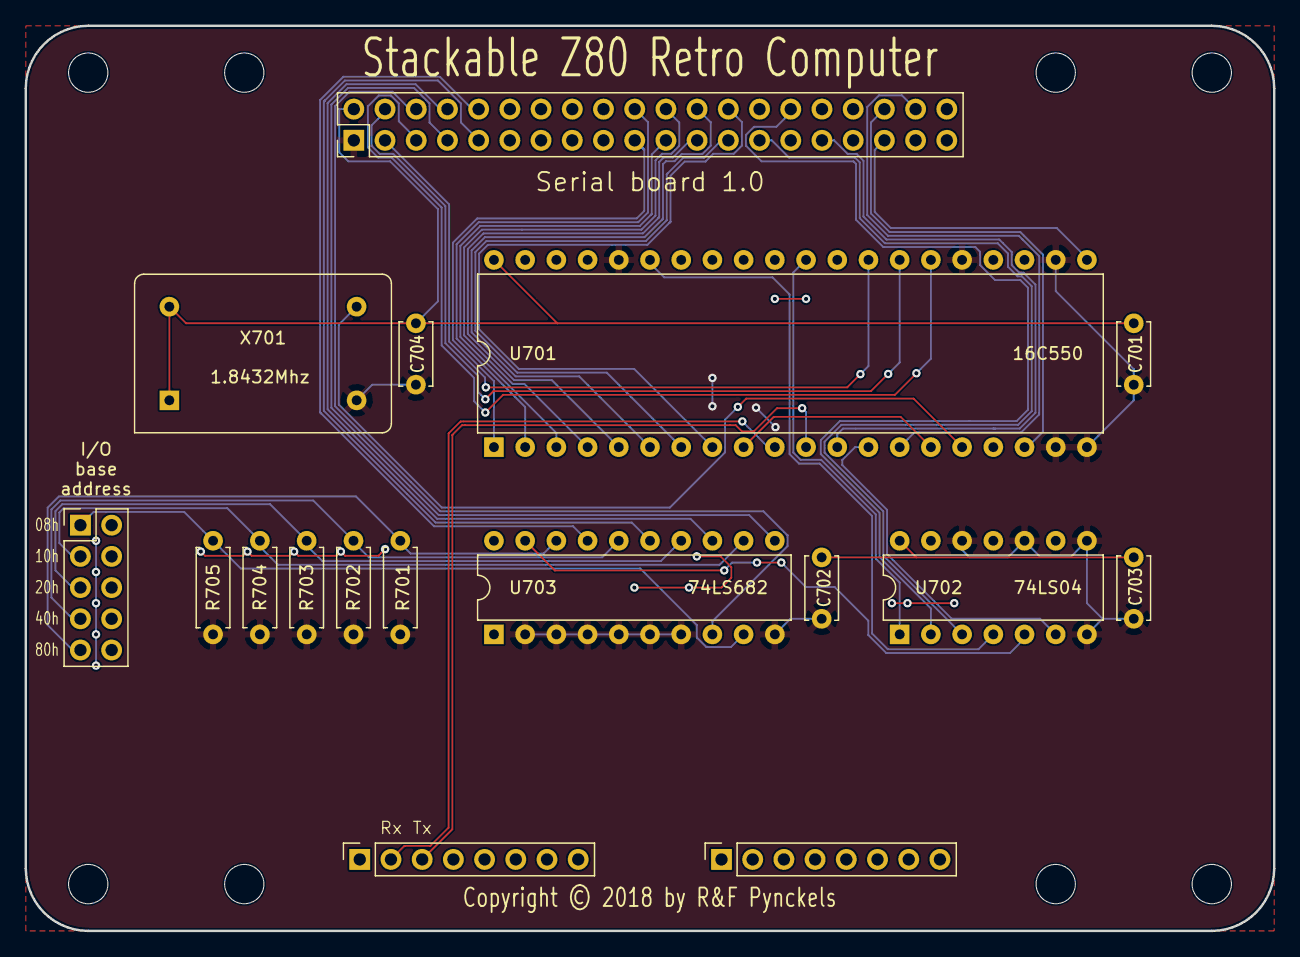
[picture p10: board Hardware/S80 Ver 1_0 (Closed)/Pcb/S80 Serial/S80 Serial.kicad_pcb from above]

Board: 2 copper layers, 101.6 x 73.7 mm, 17 parts (0 on the bottom side), 37 nets.

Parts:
C701, C702, C703, C704: 100pf; C_Disc_D5.0mm_W2.5mm_P5.00mm
J701: 02x20; PinSocket_2x20_P2.54mm_Vertical
J702, J703: 01x08; PinSocket_1x08_P2.54mm_Vertical
J704: 02x05; PinHeader_2x05_P2.54mm_Vertical
R701, R702, R703, R704, R705: 5K; R_Axial_DIN0207_L6.3mm_D2.5mm_P7.62mm_Horizontal
U701: 16C550; DIP-40_W15.24mm
U702: 74LS04; DIP-14_W7.62mm
U703: 74LS682; DIP-20_W7.62mm
X701: 1.8432Mhz; Oscillator_DIP-14

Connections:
/Breakout 2in/A0: J701.3, U701.28
/Breakout 2in/A1: J701.4, U701.27
/Breakout 2in/A2: J701.5, U701.26
/Breakout 2in/A3: J701.6, U703.8
/Breakout 2in/A4: J701.7, U703.11
/Breakout 2in/A5: J701.8, U703.13
/Breakout 2in/A6: J701.9, U703.15
/Breakout 2in/A7: J701.10, U703.17
/Breakout 2in/C0: J701.27, U702.3
/Breakout 2in/C3: J701.30, U702.2
/Breakout 2in/C4: J701.31, U701.12
/Breakout 2in/C8: J701.35, U701.21
/Breakout 2in/C9: J701.36, U701.18
/Breakout 2in/C11: J701.38, U701.14
/Breakout 2in/D0: J701.19, U701.1
/Breakout 2in/D1: J701.20, U701.2
/Breakout 2in/D2: J701.21, U701.3
/Breakout 2in/D3: J701.22, U701.4
/Breakout 2in/D4: J701.23, U701.5
/Breakout 2in/D5: J701.24, U701.6
/Breakout 2in/D6: J701.25, U701.7
/Breakout 2in/D7: J701.26, U701.8
/Breakout 2in/U1: J702.2, U701.10
/Breakout 2in/U2: J702.3, U701.11
GND: C701.1, C702.1, C703.1, C704.1, J701.1, R701.2, R702.2, R703.2, R704.2, R705.2, U701.19, U701.20, U701.22, U701.25, U701.36, U702.7, U702.8, U702.10, U702.12, U703.2, U703.3, U703.4, U703.5, U703.6, U703.7, U703.10, X701.7
unnamed: J704.1, R705.1, U703.9
unnamed: J704.3, R704.1, U703.12
unnamed: J704.5, R703.1, U703.14
unnamed: J704.7, R702.1, U703.16
unnamed: J704.9, R701.1, U703.18
unnamed: U701.13, U702.6
unnamed: U701.9, U701.15
unnamed: U701.16, X701.8
unnamed: U701.30, U702.1
unnamed: U701.35, U702.4
unnamed: U702.5, U703.19
VCC: C701.2, C702.2, C703.2, C704.2, J701.2, J704.2, J704.4, J704.6, J704.8, J704.10, U701.40, U702.14, U703.20, X701.1, X701.14

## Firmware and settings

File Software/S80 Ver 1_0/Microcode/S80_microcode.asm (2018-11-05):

;===============================================================================
;
; Project: S80_microcode
; File:    S80_microcode.asm
; Version: 1.0
;
; Author : Filip Pynckels
;
; Created: 2018 10 20
; Adapted: 2018 10 30
;
; Build tools (z88dk):
;
;		z88dk/z80asm
;		z88dk/appmake
;
; Build commands:
;
;		z80asm --cpu=z80 --list --make-bin --map S80_microcode.asm
;		appmake +glue --binfile S80_microcode --clean --ihex > /dev/null
;
; RealTerm load commands:
;
;		Display:	Ansi
;		Port:		115200,8,1,N,N + push <Change>
;		Send:		Delay=2
;
; Example input:
;
;		Run program in ROM at address 05F1:
;			:05F1::y
;
;		Run program in RAM at address F53B:
;			:F53B:<bin program file converted to hex>:y
;
;===============================================================================
;
; This program is free software. You can redistribute it and/or modify it under
; the terms of the MIT Public License.
;
; This software is distributed in the hope that it will be useful, but without
; any warranty. Without even the implied warranty of merchantability or fitness
; for a particular purpose.
;
;===============================================================================


;===============================================================================
;=   C O D E   E N T R Y   P O I N T                                           =
;===============================================================================

			org		0x0000
			jp		Microcode_Start


;===============================================================================
;=   C O N S T A N T S                                                         =
;===============================================================================

			; Memory checking constants

MEM_SIZE	equ		0x7FFF					; Memory to check for eeprom is lower 32Kb
CHK_VAL		equ		0x00					; Memory check value (!!! DO NOT FILL LAST BYTE OF EEPROM WITH VALUE )

			; Special input characters

DELIMITER	equ		':'
NO_HEX		equ		0xFF

			; String output constants

CR			equ		13						; ASCII cariage return
ESC			equ		27						; ASCII escape
LF			equ		10						; ASCII line feed
NULL		equ		 0						; ASCII null

			; UART (16C550) registers

BASEADDR	equ		0xC0					;	DLAB	A2	A1	A0 	Register
											;	----	--	--	--	--------
RX			equ		BASEADDR + 0x00			;	  0		 0	 0   0		Data in (reading),
TX			equ		BASEADDR + 0x00			;							Data out (writing)
DIVLOW		equ		BASEADDR + 0x00			;	  1		 0	 0 	 0		Divisor latch (low byte)
INTEN		equ		BASEADDR + 0x01			;	  0		 0	 0	 1		Interrupt enable
DIVHIGH		equ		BASEADDR + 0x01			;	  1		 0	 0	 1		Divisor latch (high byte)
INTID		equ		BASEADDR + 0x02			;	  X		 0	 1	 0		Interrupt identification (reading),
CTRLFIFO	equ		BASEADDR + 0x02			;							FiFo control (writing)
CTRLLINE	equ		BASEADDR + 0x03			;	  X		 0	 1	 1		Line control
CTRLMODEM	equ		BASEADDR + 0x04			;	  X		 1	 0	 0		Modem control
STATLINE	equ		BASEADDR + 0x05			;	  X		 1	 0	 1		Line status
STATMODEM	equ		BASEADDR + 0x06			;	  X		 1	 1	 0		Modem status
SCRATCH		equ		BASEADDR + 0x07			;	  X		 1	 1	 1		Scratch register

			; UART (16C550) line status bits

DR			equ		0						; Bit 0: Receiver data ready indicator
THRE		equ		5						; Bit 5: Transmitter holding register empty indicator


;===============================================================================
;=   D A T A                                                                   =
;===============================================================================

			; ANSI excape sequences
			
			; Black				ESC, "[30m"
			; Red				ESC, "[31m"
			; Green				ESC, "[32m"
			; Yellow			ESC, "[33m"
			; Blue				ESC, "[34m"
			; Magenta			ESC, "[35m"
			; Cyan				ESC, "[36m"
			; White				ESC, "[37m"
			
			; Bright Black		ESC, "[30;1m"
			; Bright Red		ESC, "[31;1m"
			; Bright Green		ESC, "[32;1m"
			; Bright Yellow		ESC, "[33;1m"
			; Bright Blue		ESC, "[34;1m"
			; Bright Magenta	ESC, "[35;1m"
			; Bright Cyan		ESC, "[36;1m"
			; Bright White		ESC, "[37;1m"
			
			; Clear screen		ESC, "[2J"
			; Cursor home		ESC, "[H"
			; Reset	color		ESC, "[0m"

HeaderStr:	defb	"S80 stackable retro Z80 computer (Ver 1.0)", CR, LF, CR, LF
			defb	"  Copyright (c) 2018 by R&F Pynckels", CR, LF
			defb	"  Open Hardware/Software under the MIT license", CR, LF, NULL

ClearScr:	defb	ESC, "[2J", ESC, "[H", ESC, "[31;1m", NULL

EEpromStr:	defb	"  ROM address range: 0x0000 - 0x", NULL
RamStr:		defb	CR, LF, "  RAM address range: 0x", NULL
RamStrSuff:	defb	" - 0xFFFF", CR, LF
			defb	ESC, "[0m", NULL

Skip2Lines:	defb	CR, LF
Skip1Line:	defb	CR, LF, NULL

LoadStr:	defb	CR, LF, "Please load an S80 program...", NULL
LoadAdStr:	defb	CR, LF, "S80 loading program at address 0x", NULL
LoadRunStr:	defb	CR, LF, "Run program (y/n)?", NULL


;===============================================================================
;=   C O D E                                                                   =
;===============================================================================

			;-------------------------------------------------------------------
			;- Get hex4 from UART 16C550                                       -
			;-                                                                 -
			;- Function: byte CharToHex ( char B )                             -
			;-                                                                 -
			;- Return values:                                                  -
			;-   B = binary value                                              -
			;-------------------------------------------------------------------
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

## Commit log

2018-11-04 Directory reorganisation
    [S80 Breakout 2in.sch, S80 Breakout 7in.sch, S80 Clock.sch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]
2018-11-05 Update S80C design
    [S80 Breakout 2in.sch, S80 Breakout 7in.sch, S80 Clock.sch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]
2018-11-07 Refresh S80 Kicad version (5.01)
    [S80 Breakout 2in.sch, S80 Breakout 7in.sch, S80 Clock.sch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]
2018-11-09 Update S80C to S80Z
    [S80C.sch, S80Z.kicad_pcb, S80Z.sch]
2018-11-11 Make S80 PCB's and Gerbers public
    [S80 Breakout 2in-B.Cu.gbl, S80 Breakout 2in-B.Mask.gbs, S80 Breakout 2in-B.SilkS.gbo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]
2018-11-11 Adding Bill of Material
    [Bill of Material.xlsx]
2018-11-12 Reorganisation directory structure
    [Template_Complete.kicad_pcb, Template_JlcPcb_Batch_Nr.kicad_pcb, Template_Mounting_Holes.kicad_pcb]
2018-11-17 Add Pynckels-kicad-library
    [S80 Template.kicad_pcb]
2018-11-17 Reorganisation kicad templates
    [S80 Template.kicad_pcb]
2018-11-17 Reorganisation Hardware directory
    [S80 Template.kicad_pcb]
2018-11-22 KiCad footprint library update
2018-11-22 Towers of Hanoi insert term.bat
2018-11-22 S80 Ver 2_0 initial upload
    [S80 Memory.sch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]
2018-11-25 S80 Memory Schematic redesign
    [S80 Memory.sch]
2018-11-25 Update kicad library
2018-11-27 Memory 2.0 change
    [S80 Memory.sch]
2018-11-29 Memory logic adjustments
    [S80 Memory.sch]
2018-12-02 S80 Ver 2_0 circuit design changes
    [S80 Memory.sch, S80 Serial.sch]

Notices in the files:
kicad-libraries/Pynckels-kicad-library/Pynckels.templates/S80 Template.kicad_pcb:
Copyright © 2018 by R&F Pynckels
